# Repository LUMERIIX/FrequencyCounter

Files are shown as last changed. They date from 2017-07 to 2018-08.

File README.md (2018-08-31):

# FrequencyCounter - The most powerfull DIY FrequnecyCounter
## Introduction
FrequencyCounter is a soft- and hardware project which is a FPGA based FrequencyCounter. The FrequencyCounter is controlled by an GUI Interface ([SigrokLcd](https://github.com/LUMERIIX/SigrokLcd) )on the usb connected Host-PC. A single USB cable for Data and Power supply keeps the construction simple and clean as possible. The GUI is custom-made for this project behind the GUI runs [Sigrok](https://sigrok.org/) a open-source tool for controlling measure devices like frequency counters, multimeters, oscilloscopes etc. The project aims to be a simple, cheap, useful and accurate measure device for everyone. The layout is made in [KiCad]( http://kicad-pcb.org/) a open-source layout tool. The Project is open and everyone is wellcome to work on this project and contribute his extensions and improvements.

## Concept
Comming Soon!

## Hardware
The Hardware is based on a Spartan 6 FPGA which is the heartpiece of the entire circuit. The circuit is reduced to its minimal. The PCB ist a four-layer 1.6mm thick FR4 Board which makes it more expensive but the layout is much cleaner and the signal quality can be increased. The PCB has mounted components on top and bottom site of it. The Mounting on the bottom site is reduced to the minimal to keep it simple an allows also the use without a hosing.<br> 

### Housing
I created a simple and clean plexiglas housing for the PCB which fits the style of the prject very well. The design of the housing is inspired by the [Sick of Beige](http://dangerousprototypes.com/docs/Sick_of_Beige_compatible_cases) cases.<br> 

### Internal Clock Reference
The mouting of the Circuit give you the choice to mout the expensive **OCXO**(Oven Controlled Oscillator) or the way cheaper **VCTCXO**(Voltage Controller Temperatur Compensated Oscillator). In fact of this the precicion of the tool is scalable but I recommend you to mount the cheaper option because the difference in the accuracy is not as much as the price difference. <br>

### Input Circuits
The Input Circuits of each channel are different because not one of them fit in all usage situations.<br> 
The input circuit of **CHA** is realized with an voltage limiter and a HP-Filter at the inlet, followed by a divider (/8) with a HP-Filter and a voltage divider at the output to change the bias point. The change of the bias point is neccessary for the fpga to allow the signal detection.<br>
The most complex incput circuit is the one of the **external reference** (Ext.Ref). The circuit is out of the LTC6957 Datasheet and is often used for reference clocks. The transformator at the inlet make it impossible to use this circuit for both other channels of the FrequencyCounter (frequnecy reasons).<br>
**Channel B** is simpler than the other input ciruits. After the inlet it follows a voltage limiter and a very-fast comparator for edge detecting.<br>
### Communication
The Communication of the Device is over USB/UART through this its possible to have only one cable for programming, powersupply and also communication. On the PCB of the Counter a FTDI (FT2232) is mounted. Through this chip it's possible to programm the FPGA with JTAG and also have a USART Bus to the FPGA for the communication and the data. The Protocol which is used for the controlling consits only out of one command-byte which controls the hole device. The Commands you see in the Command Overview.<br>
**Command Overview**<br><br>
<br><br>
**Communication Overview**<br><br>
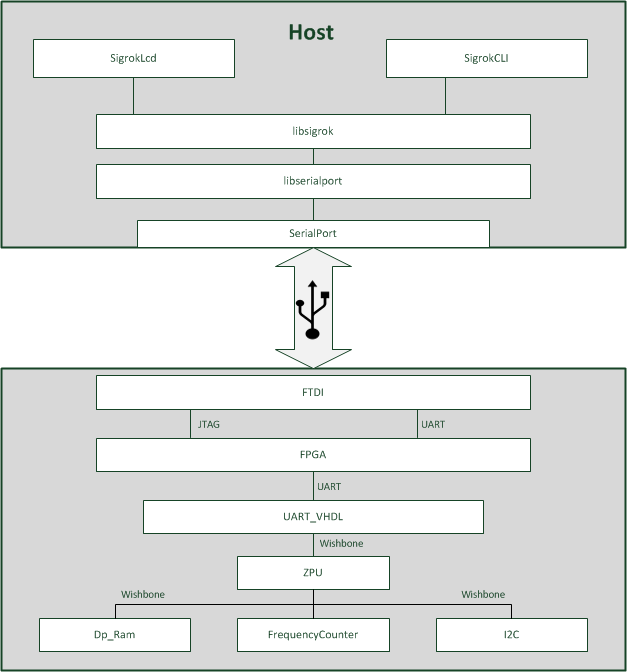
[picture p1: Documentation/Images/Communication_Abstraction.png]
<br>

### Hardware Overview:<br>
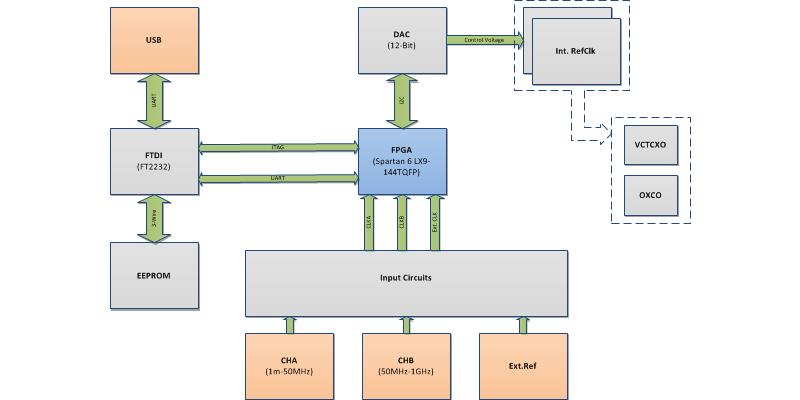
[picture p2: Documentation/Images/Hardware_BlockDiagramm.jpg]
<br>

## Software
### VHDL
**UART**<br>
The UART component isn't self written it is a adjusted version of the [UART component of Scott Larson](https://eewiki.net/pages/viewpage.action?pageId=59507062) of the eewiki. The component was extended by a Wishbone Interface to fit the projects architecture. The UART interface is used for the communication with the host-pc.<br><br>
**I2C**<br>
The I2C Master Component is also not self written it's base is from [opencores](https://opencores.org/project,i2c?do=projects&download=i2c). The component works fine and it's a big advantage to have a originally wishbone interface included. I2C is in the FrequnecyCounter used to control the DAC wich provides to control voltage for the oscillators.<br><br>
**ZPU**<br>
The [ZPU](https://github.com/zylin/zpu) is a open-source VHDL project from github wich includes a small 32bit CPU. The base ZPU Repo consist of different cores and testbenches but is very confusing. In fact of this I created a fork of the repo and set up a [working base](https://github.com/LUMERIIX/zpu) for the FrequencyCounter Project.<br><br>
**FrequencyCounter**<br>
The FrequencyCounter VHDL Code is the main part which counts our signals. The FrequencyCounter includes a ChannelSelctor which connect the desired Channels to the Counter itself. Furthermore the component includes a GateTimeGenerator which open a Countergate for a selected duration of time. The Signals are counted simultaneously with two identical VHDL counters. Each counter counts the amout of signal periods in this GateTime. Through the knowledge of the constant reference and the countervalue of the Reference Clock we can calculate the frequency of the unknown signal. This kind of Counter is called [Recirprocal Counter](https://en.wikipedia.org/wiki/Frequency_counter).<br><br>
**Procedure & Calculation**<br><br>
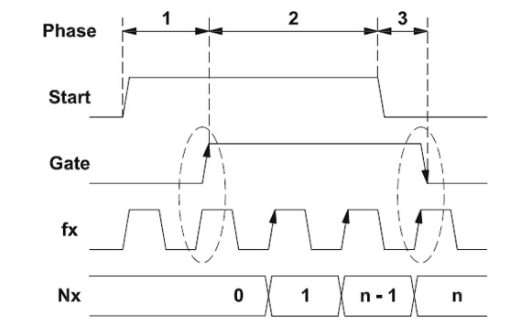
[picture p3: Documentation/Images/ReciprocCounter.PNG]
<br><br>

<br><br><br><br><br><br><br><br><br><br>

**VHDL Abstraction**<br><br>
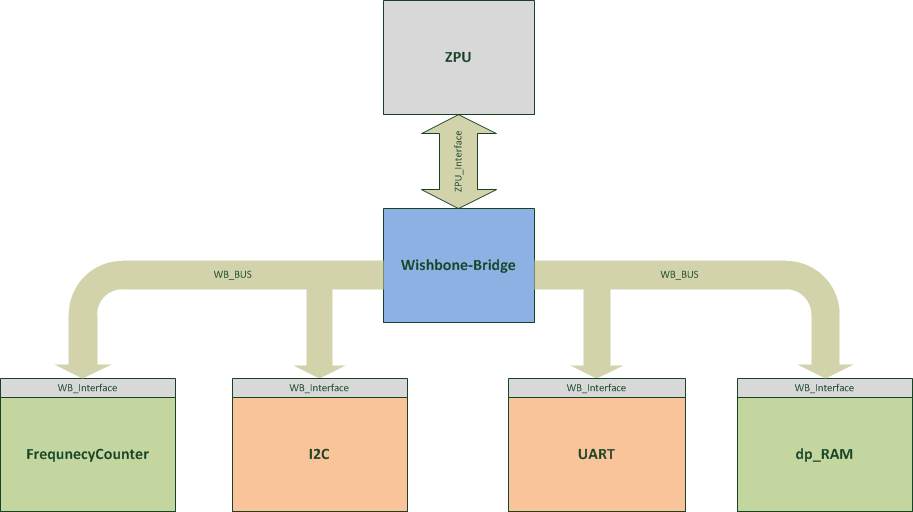
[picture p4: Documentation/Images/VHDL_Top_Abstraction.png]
<br><br>
**VHDL FrequencyCounter Abstraction**<br><br>
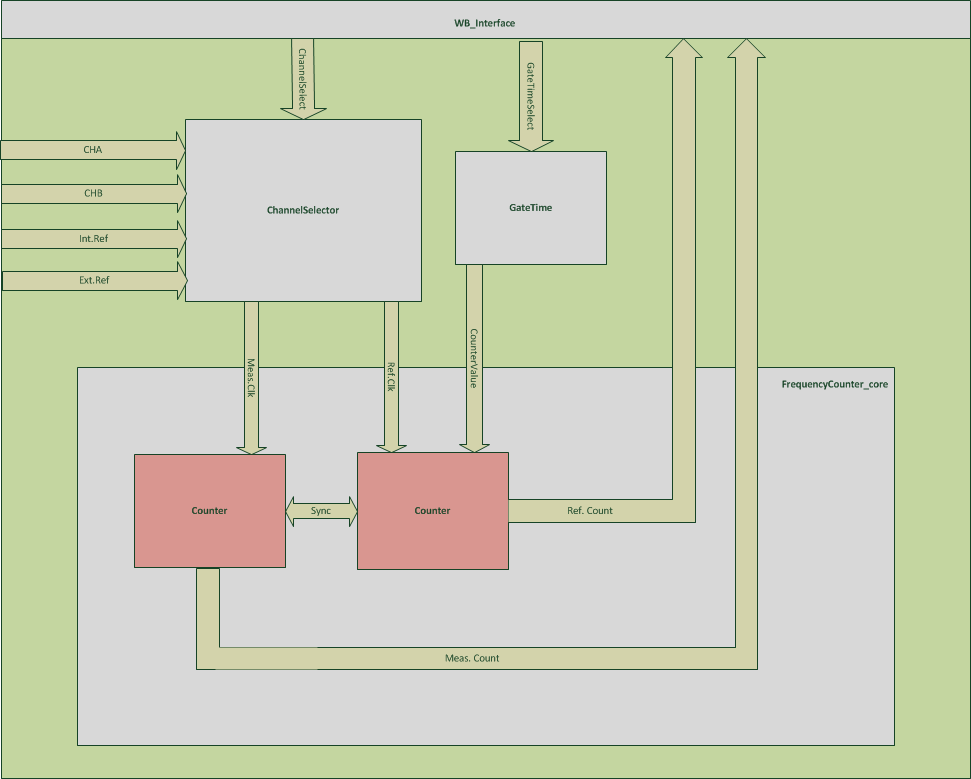
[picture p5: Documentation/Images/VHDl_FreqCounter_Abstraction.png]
<br>
### C-Code
The C-Code is the Programm Code for the implemented VHDL CPU [ZPU](https://github.com/zylin/zpu) or a so called [SOC](https://en.wikipedia.org/wiki/System_on_a_chip)(System-on-a-Chip). The C-Code implements the Protocol for the communication over uart and i2c. The ZPU also controls the entire VHDL Components and handles the data. The Code is obviously written in C and is based on a state-machine. The C-Code is converted in a dualported-RAM (VHDL Component) which is located in the VHDL Project and is connected to the Wishbone-Bus of the ZPU. 

## Download & Installation
**It's recommended to use a Linux Host-PC the project is tested and developt on Fedora 27 so I recommend to install a Fedora VM in VMWare Worksation**

```
cd
gedit .bashrc
```
Add following lines:
```
export PKG_CONFIG_PATH=/usr/local/lib/pkgconfig/ 
export PYTHONPATH=/usr/local/lib64/python2.7/site-packages/
```
Save and Close gedit.<br>
Install dependencies:
```
sudo dnf install gcc-gfortran apr-devel apr-util-devel octave*
sudo dnf install gcc-c++
sudo dnf update
sudo dnf upgrade
sudo svn git cppunit-devel rabbitvcs*
sudo dnf copr enable jenslody/codeblocks
sudo dnf install codeblocks codeblocks-contrib
sudo dnf install libftdi-devel libusb-devel xterm
sudo dnf install automake libtool autoconf make cmake autoconf-archive pkgconfig glib2-devel libzip-devel check-devel doxygen
sudo dnf install glibmm24-devel python-devel numpy pygobject3-devel swig
sudo dnf install redhat-rpm-config python3-devel qt5 qt5-devel boost-devel
```
Next Install libserialport and the adjusted version of libsigrok:
```
git clone git://sigrok.org/libserialport
cd /libserialport
./autogen.sh 
./configure
make
sudo make install

git clone https://github.com/LUMERIIX/libsigrok_FreqCount
cd libsigrok_FreqCount
./autogen.sh
PKG_CONFIG_PATH=/usr/local/lib/pkgconfig/ ./configure 
make -j4
sudo PKG_CONFIG_PATH=/usr/local/lib/pkgconfig/ PYTHONPATH=/usr/local/lib64/python2.7/site-packages/ make install
sudo ldconfig /usr/local/lib
```
Download the FrequencyCounter Repo:
```
git clone https://github.com/LUMERIIX/FrequencyCounter
cd FrequencyCounter 
```
**Optional** Download the fork of the ZPU Repo to have all source files 
```
cd
git clone https://github.com/LUMERIIX/zpu
```
The source files are located under
```
cd zpu/zpu/hdl/zpu4
```
Next Install openocd for flashing the bitstream:
```
sudo dnf install git libtool autoconf texinfo libusb-dev
sudo dnf install libftdi
cd
git clone git://git.code.sf.net/p/openocd/code openocd
cd ~/openocd
./bootstrap
./configure --enable-maintainer-mode --disable-werror --enable-ftdi
make
sudo make install
```
Create Directory for Config files of Openocd
```
cd ~
mkdir openocd-bin
cd ~/openocd/tcl
cp -r * ~/openocd-bin
cd ../src
cp openocd ~/openocd-bin
```
Add the Interface Config file for the FT2232
```
cd 
cp FrequnecyCounter/FTDI/ft2232-jtag.cfg openocd-bin/interface/ftdi
```
Download [SigrokLcd](https://github.com/LUMERIIX/SigrokLcd) or [SigrokCLI](https://sigrok.org/wiki/Linux)

### Set up the FTDI Chip (FT2232d)
First download [FT_PROG](http://www.ftdichip.com/Support/Utilities.htm#FT_PROG) and install it on your Host-pc.<br>
Open FT_PROG and Load FrequencyCounter.xml Template from directrory /FrequnceyCounter/Documentation/FrequencyCounter_Template.xml<br>
Connect your FrequencyCounter via USB to the Host-PC and power it!<br>
**Check first the Voltages of the Powersupply on the PCB to make sure the circuit is working correctly!**<br>
Scan for Devices (Devices --> Scan&Parse)<br>
A Device with Chip Type: FT2232D should be listed in the Device Tree on the left.<br>
Program Template on FTDI Chip (Devices --> Program)<br>
Now your FTDI Chip should be set-up correctly
Else take a look in the [FT_PROG manual](http://www.ftdichip.com/Support/Documents/AppNotes/AN_124_User_Guide_For_FT_PROG.pdf)

## How to use it
The actual bitstream you find under /bitstream:
```
cd
cd FrequencyCounter/bitstream
```
To flash the bitstream move to the openocd directory
```
cd
cd openocd
mdkdir bitstream
cp ../FrequencyCounter/bitstream/frequencycountertop.bit bitstream
```
Flash Command
```
openocd -f interface/ftdi/ft2232-jtag.cfg -f cpld/xilinx-xc6s.cfg -c "init; xc6s_program xc6s.tap; pld load 0 bitstream/frequnecycountertop.bit; exit"
```
**If a error is thrown try it as root.
And change write permission of the USB port where the Hardware is connected and try again!**

Open SigrokLcd and try to get some Data
```
cd
cd SigrokLcd/bin/Release
./SigrokLcd
```
If the GUI doesn't exit and you can finish the configuration of the connection in SigrokLcd you handled the bigest step. 
The Preset for the ChannelSelect is on CHA so you should receive a Frequency of quite a feq MHz. This Frequency exists through the output voltage swing of the frequency divider.<br>
**Congrats it seems that your DIY FrequencyCounter works!**

### Contact
If you have a Problem, a improvment or need Information don't hesitate to contact me.<br>
email: lukas.jenni@hotmail.de

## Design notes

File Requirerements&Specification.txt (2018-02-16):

Requirements&Specification 			-- Frequencycounter

-Frequencyrange: 					1mHz - 1GHz  						//Reduktion des Bereiches auf 500MHz möglich 
-PowerSupply: 						USB (Typ. B) => 	5V				
-Timebase options: 					ext. Reference 	 / int. Reference
-FPGA Clock: 						10MHz					
-InputVoltageRange: 				20mVpp - 5Vpp
-Signaltransfer DEVICE-PC: 			UART / JTAG							//FT2232
-DAC with eeprom:					ControllVoltageOCXO					//Aus FOM
-Quarz UART/USB: 					8MHz,12MHz							//seperater Quarz zum Betrieb der Schnittstelle
-FrequencyDisplay: 					Frequencycounter GUI
-Timebase intern: 					calibratable TCXO, OCXO				//10MHz
-Power:								max. 2.5W
-VoltageRegulator:					3.3V								//PowerSupply FPGA

Inputs:
Channel A							=> 1mHz - 50MHz
Channel B							=> 50MHz - 1GHz
Channel Ext. Ref

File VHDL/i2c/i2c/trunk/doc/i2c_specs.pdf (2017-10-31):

I

2

# C-Master Core Specification

# Author: Richard Herveille

### rherveille@opencores.org

### Rev. 0.9 July 3, 2003

## This page has been intentionally left blank

### Revision History

Rev. | Date | Author | Description
0.1 | 17/02/01 | Richard Herveille | First draft release
0.2 | 01/03/01 | Richard Herveille | Some cleaning up throughout the document Added ‘Programming Examples’ section
0.3 | | Richard Herveille | Added some comments after core-changes - added BUSY bit (status register) - changed I2C IO for ASIC support - added comment for FGPA IO
0.4 | 10/19/01 | Richard Herveille | Changed core’s databus size to 8bit. Changed documentation to reflect changes. Changed port names to new naming convention.
0.5 | 18/02/02 | Richard Herveille | Changed table headers. Added OpenCores logo.
0.5a | 05/02/02 | Richard Herveille | Reviewed entire document.
0.6 | 21/03/02 | Richard Herveille | Added Appendix A, Synthesis Results
0.7 | 25/06/02 | Richard Herveille | Changed Prescale Register formula
0.8 | 30/12/02 | Richard Herveille | Added Multi-Master capabilities. New timing diagrams.
0.9 | 03/07/03 | Richard Herveille | Changed ‘0x5C’ to ‘0xAC’ in Example1. Changed ‘RW’ to ‘W’ in Command Register. Changed ‘RW’ to ‘W’ in Transmit Register.

OpenCores | I²
C-Master core | 7/3/2003
www.opencores.org | Rev 0.8 Preliminary | 1 of 15

1

# Introduction

I

2
C is a two-wire, bi-directional serial bus that provides a simple and efficient method of data exchange between devices. It is most suitable for applications requiring occasional communication over a short distance between many devices. The I²
C standard is a true
multi-master bus including collision detection and arbitration that prevents data corruption if two or more masters attempt to control the bus simultaneously.

The interface defines 3 transmission speeds:
- Normal: 100Kbps
- Fast: 400Kbps
- High speed: 3.5Mbps

Only 100Kbps and 400Kbps modes are supported directly. For High speed special IOs are needed. If these IOs are available and used, then High speed is also supported.

## FEATURES

- Compatible with Philips I²
C standard
- Multi Master Operation
- Software programmable clock frequency
- Clock Stretching and Wait state generation
- Software programmable acknowledge bit
- Interrupt or bit-polling driven byte-by-byte data-transfers
- Arbitration lost interrupt, with automatic transfer cancelation
- Start/Stop/Repeated Start/Acknowledge generation
- Start/Stop/Repeated Start detection
- Bus busy detection
- Supports 7 and 10bit addressing mode
- Operates from a wide range of input clock frequencies
- Static synchronous design
- Fully synthesizable

2

# IO ports

## 2.1 Core Parameters

Parameter | Type | Default | Description
ARST_LVL | Bit | 1’b0 | Asynchronous reset level

### 2.1.1 ARST_LVL

The asynchronous reset level can be set to either active high (1’b1) or active low (1’b0).

## 2.2 WISHBONE interface signals

Port | Width | Direction | Description
wb_clk_i | 1 | Input | Master clock
wb_rst_i | 1 | Input | Synchronous reset, active high
arst_i | 1 | Input | Asynchronous reset
wb_adr_i | 3 | Input | Lower address bits
wb_dat_i | 8 | Input | Data towards the core
wb_dat_o | 8 | Output | Data from the core
wb_we_i | 1 | Input | Write enable input
wb_stb_i | 1 | Input | Strobe signal/Core select input
wb_cyc_i | 1 | Input | Valid bus cycle input
wb_ack_o | 1 | Output | Bus cycle acknowledge output
wb_inta_o | 1 | Output | Interrupt signal output

The core features a WISHBONE RevB.3 compliant WISHBONE Classic interface. All output signals are registered. Each access takes 2 clock cycles.
arst_i is not a WISHBONE compatible signal. It is provided for FPGA implementations. Using [arst_i] instead of [wb_rst_i] can result in lower cell-usage and higher performance, because most FPGAs provide a dedicated asynchronous reset path. Use either [arst_i] or [wb_rst_i], tie the other to a negated state.

## 2.3 External connections

Port | Width | Direction | Description
scl_pad_i | 1 | Input | Serial Clock line input
scl_pad_o | 1 | Output | Serial Clock line output
scl_pad_oe | 1 | Output | Serial Clock line output enable
sda_pad_i | 1 | Input | Serial Data line input
sda_pad_o | 1 | Output | Serial Data line output
sda_pad_oe | 1 | Output | Serial Data line output enable

The I²
C interface uses a serial data line (SDA) and a serial clock line (SCL) for data transfers. All devices connected to these two signals must have open drain or open collector outputs. Both lines must be pulled-up to VCC by external resistors.

The tri-state buffers for the SCL and SDA lines must be added at a higher hierarchical level. Connections should be made according to the following figure:

For FPGA designs the compiler can automatically insert these buffers using the following VHDL code:

scl <= scl_pad_o when (scl_padoen_oe = ‘0’) else ‘Z’;
sda <= sda_pad_o when (sda_padoen_oe = ‘0’) else ‘Z’;
scl_pad_i <= scl;
scl_pad_i <= sda;

Verilog code:

assign scl = scl_padoen_oe ? 1’bz : scl_pad_o; assign sda = sda_padoen_oe ? 1’bz: sda_pad_o; assign scl_pad_i = scl;
assign sda_pad_i = sda;

scl_pad_i

scl_pad_o

scl_padoen_o
sda_pad_i

sda_pad_o

sda_padoen_o

SCL

SDA

3

# Registers

## 3.1 Registers list

Name | Address | Width | Access | Description
PRERlo | 0x00 | 8 | RW | Clock Prescale register lo-byte
PRERhi | 0x01 | 8 | RW | Clock Prescale register hi-byte
CTR | 0x02 | 8 | RW | Control register
TXR | 0x03 | 8 | W | Transmit register
RXR | 0x03 | 8 | R | Receive register
CR | 0x04 | 8 | W | Command register
SR | 0x04 | 8 | R | Status register

## 3.2 Register description

### 3.2.1 Prescale Register

This register is used to prescale the SCL clock line. Due to the structure of the I² C
interface, the core uses a 5*SCL clock internally. The prescale register must be programmed to this 5*SCL frequency (minus 1). Change the value of the prescale register only when the ‘EN’ bit is cleared.

Example: wb_clk_i = 32MHz, desired SCL = 100KHz
1 | 63 ( | ) | 3 ( | ) 5 100
32 | dec | F hex
KHz
MHz prescale | − = | = ∗ =

Reset value: 0xFFFF

### 3.2.2 Control register

Bit # | Access | Description
7 | RW | EN, I² C core enable bit. When set to ‘1’, the core is enabled. When set to ‘0’, the core is disabled.
6 | RW | IEN, I² C core interrupt enable bit. When set to ‘1’, interrupt is enabled. When set to ‘0’, interrupt is disabled.
5:0 | RW | Reserved
Reset Value: 0x00

The core responds to new commands only when the ‘EN’ bit is set. Pending commands are finished. Clear the ‘EN’ bit only when no transfer is in progress, i.e. after a STOP command, or when the command register has the STO bit set. When halted during a transfer, the core can hang the I²
C bus.

### 3.2.3 Transmit register

Bit # | Access | Description
7:1 | W | Next byte to transmit via I² C
0 | W | In case of a data transfer this bit represent the data’s LSB. In case of a slave address transfer this bit represents the RW bit. ‘1’ = reading from slave ‘0’ = writing to slave

Reset value: 0x00

### 3.2.4 Receive register

Bit # | Access | Description
7:0 | R | Last byte received via I² C
Reset value: 0x00

### 3.2.5 Command register

Bit # | Access | Description
7 | W | STA, generate (repeated) start condition
6 | W | STO, generate stop condition
5 | W | RD, read from slave
4 | W | WR, write to slave
3 | W | ACK, when a receiver, sent ACK (ACK = ‘0’) or NACK (ACK = ‘1’)
2:1 | W | Reserved
0 | W | IACK, Interrupt acknowledge. When set, clears a pending interrupt.
Reset Value: 0x00

The STA, STO, RD, WR, and IACK bits are cleared automatically. These bits are always read as zeros.

### 3.2.6 Status register

Bit # | Access | Description
7 | R | RxACK, Received acknowledge from slave. This flag represents acknowledge from the addressed slave. ‘1’ = No acknowledge received ‘0’ = Acknowledge received
6 | R | Busy, I² C bus busy ‘1’ after START signal detected ‘0’ after STOP signal detected
5 | R | AL, Arbitration lost This bit is set when the core lost arbitration. Arbitration is lost when: • a STOP signal is detected, but non requested • The master drives SDA high, but SDA is low. See bus-arbitration section for more information.
4:2 | R | Reserved
1 | R | TIP, Transfer in progress. ‘1’ when transferring data ‘0’ when transfer complete
0 | R | IF, Interrupt Flag. This bit is set when an interrupt is pending, which will cause a processor interrupt request if the IEN bit is set. The Interrupt Flag is set when: • one byte transfer has been completed • arbitration is lost

Reset Value: 0x00

Please note that all reserved bits are read as zeros. To ensure forward compatibility, they should be written as zeros.

4

# Operation

## 4.1 System Configuration

The I²
C system uses a serial data line (SDA) and a serial clock line (SCL) for data transfers. All devices connected to these two signals must have open drain or open collector outputs. The logic AND function is exercised on both lines with external pull-up resistors.

Data is transferred between a Master and a Slave synchronously to SCL on the SDA line on a byte-by-byte basis. Each data byte is 8 bits long. There is one SCL clock pulse for each data bit with the MSB being transmitted first. An acknowledge bit follows each transferred byte. Each bit is sampled during the high period of SCL; therefore, the SDA line may be changed only during the low period of SCL and must be held stable during the high period of SCL. A transition on the SDA line while SCL is high is interpreted as a command (see START and STOP signals).

## 4.2 I² C Protocol

Normally, a standard communication consists of four parts:
1) START signal generation
2) Slave address transfer
3) Data transfer
4) STOP signal generation
S | A7 | A6 | A5 | A4 | A3 | A2 | A1 | RW ACK | D7 | D6 | D5 | D4 | D3 | D2 | D1 | D0 NACK | P

SCL

SDA

1 | 2 | 3 | 4 | 5 | 6 | 7 | 8 | 9
MSB | LSB
1 | 2 | 3 | 4 | 5 | 6 | 7 | 8 | 9
MSB | LSB

### 4.2.1 START signal

When the bus is free/idle, meaning no master device is engaging the bus (both SCL and SDA lines are high), a master can initiate a transfer by sending a START signal. A START signal, usually referred to as the S-bit, is defined as a high-to-low transition of SDA while SCL is high. The START signal denotes the beginning of a new data transfer. A Repeated START is a START signal without first generating a STOP signal. The master uses this method to communicate with another slave or the same slave in a different transfer direction (e.g. from writing to a device to reading from a device) without releasing the bus.

The core generates a START signal when the STA-bit in the Command Register is set and the RD or WR bits are set. Depending on the current status of the SCL line, a START or Repeated START is generated.

### 4.2.2 Slave Address Transfer

The first byte of data transferred by the master immediately after the START signal is the slave address. This is a seven-bits calling address followed by a RW bit. The RW bit signals the slave the data transfer direction. No two slaves in the system can have the same address. Only the slave with an address that matches the one transmitted by the master will respond by returning an acknowledge bit by pulling the SDA low at the 9th SCL clock cycle.

Note: The core supports 10bit slave addresses by generating two address transfers. See the Philips I²
C specifications for more details.

The core treats a Slave Address Transfer as any other write action. Store the slave device’s address in the Transmit Register and set the WR bit. The core will then transfer the slave address on the bus.

### 4.2.3 Data Transfer

Once successful slave addressing has been achieved, the data transfer can proceed on a byte-by-byte basis in the direction specified by the RW bit sent by the master. Each transferred byte is followed by an acknowledge bit on the 9th SCL clock cycle. If the slave signals a No Acknowledge, the master can generate a STOP signal to abort the data transfer or generate a Repeated START signal and start a new transfer cycle.

If the master, as the receiving device, does not acknowledge the slave, the slave releases the SDA line for the master to generate a STOP or Repeated START signal.

To write data to a slave, store the data to be transmitted in the Transmit Register and set the WR bit. To read data from a slave, set the RD bit. During a transfer the core set the TIP flag, indicating that a Transfer is In Progress. When the transfer is done the TIP flag is reset, the IF flag set and, when enabled, an interrupt generated. The Receive Register contains valid data after the IF flag has been set. The user may issue a new write or read command when the TIP flag is reset.

### 4.2.4 STOP signal

The master can terminate the communication by generating a STOP signal. A STOP signal, usually referred to as the P-bit, is defined as a low-to-high transition of SDA while SCL is at logical ‘1’.

## 4.3 Arbitration Procedure

### 4.3.1 Clock Synchronization

The I²
C bus is a true multimaster bus that allows more than one master to be connected on it. If two or more masters simultaneously try to control the bus, a clock synchronization procedure determines the bus clock. Because of the wired-AND connection of the I²
C signals a high to low transition affects all devices connected to the bus. Therefore a high to low transition on the SCL line causes all concerned devices to count off their low period. Once a device clock has gone low it will hold the SCL line in that state until the clock high state is reached. Due to the wired-AND connection the SCL line will therefore be held low by the device with the longest low period, and held high by the device with the shortest high period.

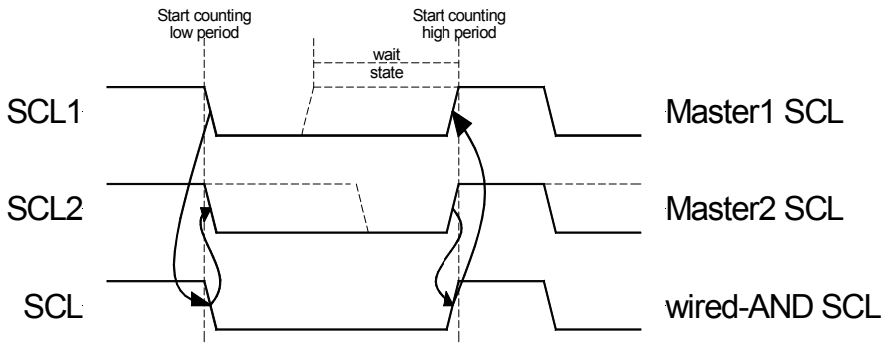
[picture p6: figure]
Start counting low period; wait state; Start counting high period; SCL1; SCL2; SCL; Master1 SCL; Master2 SCL; wired-AND SCL

### 4.3.2 Clock Stretching

Slave devices can use the clock synchronization mechanism to slow down the transfer bit rate. After the master has driven SCL low, the slave can drive SCL low for the required period and then release it. If the slave’s SCL low period is greater than the master’s SCL low period, the resulting SCL bus signal low period is stretched, thus inserting wait-states.

5

# Architecture

The I2C core is built around four primary blocks; the Clock Generator, the Byte Command Controller, the Bit Command Controller and the DataIO Shift Register. All other blocks are used for interfacing or for storing temporary values.

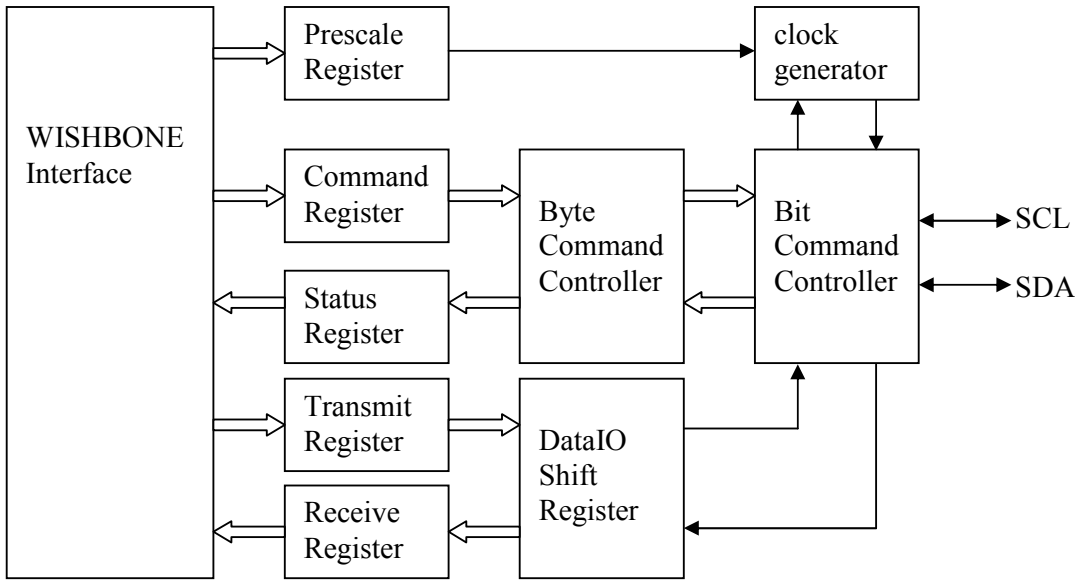
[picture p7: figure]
SCL; SDA; Prescale Register; clock generator; Command Register; Status Register; Byte Command Controller; Bit Command Controller; WISHBONE Interface; Transmit Register; Receive Register; DataIO Shift Register

## 5.1 Clock Generator

The Clock Generator generates an internal 4*Fscl clock enable signal that triggers all synchronous elements in the Bit Command Controller. It also handles clock stretching needed by some slaves.

## 5.2 Byte Command Controller

The Byte Command Controller handles I2C traffic at the byte level. It takes data from the Command Register and translates it into sequences based on the transmission of a single byte. By setting the START, STOP, and READ bit in the Command Register, for example, the Byte Command Controller generates a sequence that results in the

Fig. 5.1 Internal structure I2C Master Core

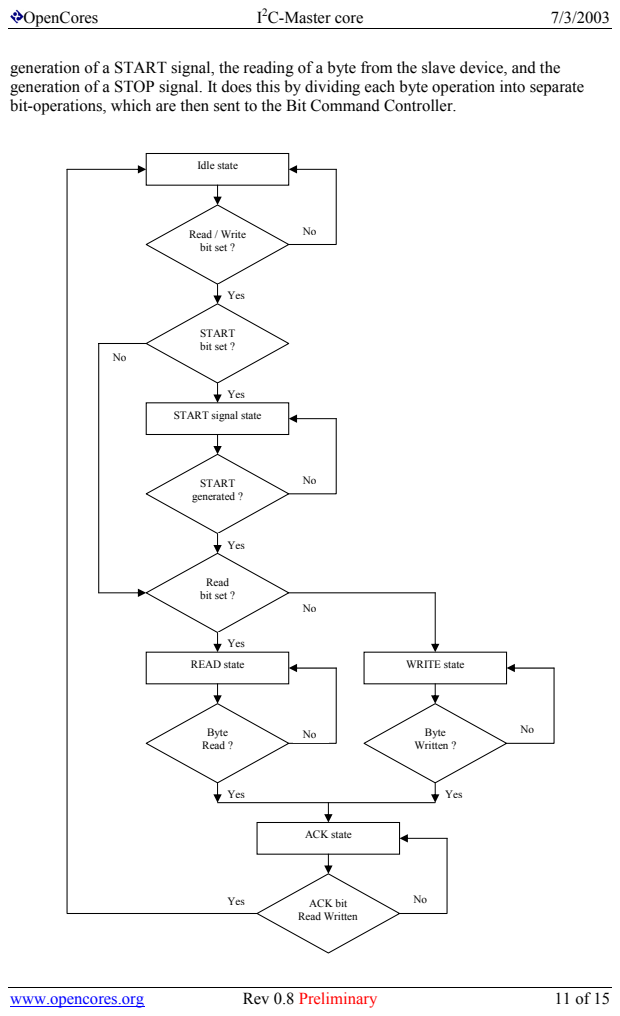
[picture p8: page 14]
Idle state; Read / Write bit set ?; Yes; START bit set ?; Read bit set ?; READ state; Byte Read ?; ACK state; WRITE state; Byte Written ?; ACK bit Read Written

generation of a START signal, the reading of a byte from the slave device, and the
generation of a STOP signal. It does this by dividing each byte operation into separate
bit-operations, which are then sent to the Bit Command Controller.

START signal state

START generated ?

## 5.3 Bit Command Controller

The Bit Command Controller handles the actual transmission of data and the generation of the specific levels for START, Repeated START, and STOP signals by controlling the SCL and SDA lines. The Byte Command Controller tells the Bit Command Controller which operation has to be performed. For a single byte read, the Bit Command Controller receives 8 separate read commands. Each bit-operation is divided into 5 pieces (idle and A, B, C, and D), except for a STOP operation which is divided into 4 pieces (idle and A, B, and C).

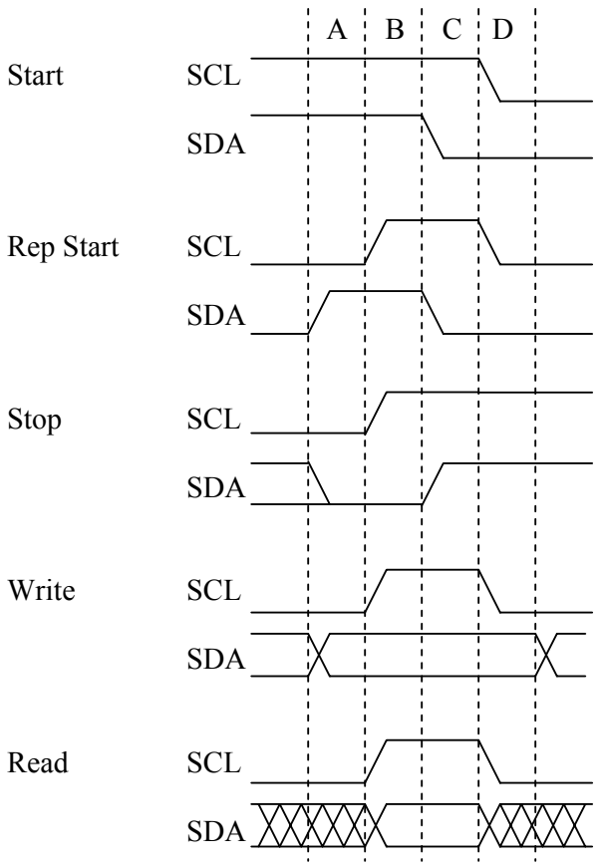
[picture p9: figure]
Start; SCL; SDA; Rep Start; Stop; Write; Read

## 5.4 DataIO Shift Register

The DataIO Shift Register contains the data associated with the current transfer. During a read action, data is shifted in from the SDA line. After a byte has been read the contents are copied into the Receive Register. During a write action, the Transmit Register’s contents are copied into the DataIO Shift Register and are then transmitted onto the SDA line.

6

# Programming examples

## Example 1

Write 1 byte of data to a slave.

Slave address = 0x51 (b”1010001”) Data to write = 0xAC

I2C Sequence:
1) generate start command
2) write slave address + write bit
3) receive acknowledge from slave
4) write data
5) receive acknowledge from slave
6) generate stop command

Commands:
1) write 0xA2 (address + write bit) to Transmit Register, set STA bit, set WR bit. -- wait for interrupt or TIP flag to negate --
2) read RxACK bit from Status Register, should be ‘0’.
write 0xAC to Transmit register, set STO bit, set WR bit.
-- wait for interrupt or TIP flag to negate --
3) read RxACK bit from Status Register, should be ‘0’.

Please note that the time for the Interrupt Service Routine is not shown here. It is assumed that the ISR is much faster then the I²
C cycle time, and therefore not visible.

## Example 2

Read a byte of data from an I2C memory device.

Slave address = 0x4E
Memory location to read from = 0x20

I2C sequence:
1) generate start signal
2) write slave address + write bit
3) receive acknowledge from slave
4) write memory location
5) receive acknowledge from slave
6) generate repeated start signal
7) write slave address + read bit
8) receive acknowledge from slave
9) read byte from slave
10) write no acknowledge (NACK) to slave, indicating end of transfer
11) generate stop signal

Commands:
1) write 0x9C (address + write bit) to Transmit Register, set STA bit, set WR bit. -- wait for interrupt or TIP flag to negate --
2) read RxACK bit from Status Register, should be ‘0’.
write 0x20 to Transmit register, set WR bit.
-- wait for interrupt or TIP flag to negate --
3) read RxACK bit from Status Register, should be ‘0’.
write 0x9D (address + read bit) to Transmit Register, set STA bit, set WR bit. -- wait for interrupt or TIP flag to negate --
4) set RD bit, set ACK to ‘1’ (NACK), set STO bit

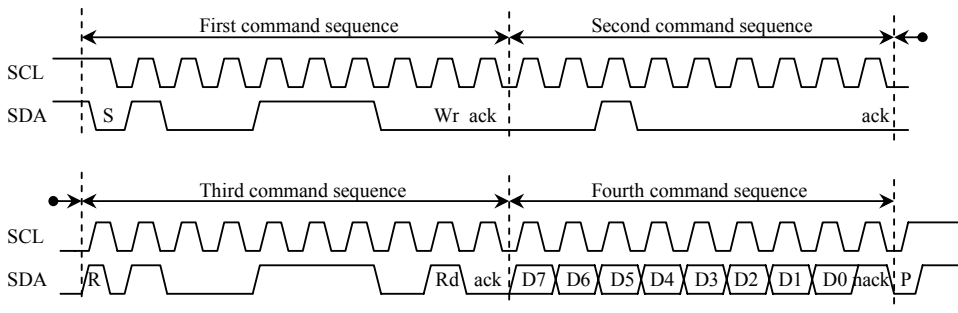
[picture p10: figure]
First command sequence; Second command sequence; SDA; Wr ack; ack; SCL; Third command sequence; Fourth command sequence

Please note that the time for the Interrupt Service Routine is not shown here. It is assumed that the ISR is much faster then the I²
C cycle time, and therefore not visible.
SDA | R | Rd ack | D7 D6 D5 D4 D3 D2 D1 D0 nack | P

# Appendix A

# Synthesis results

Synthesis tool: Synplify Pro

Technology | Device | Speed grade | Fmax | Resource usage
ACTEL | A54SX16ATQ100 | std | 58MHz | Modules: 352
Altera | EP10K50ETC144 | -3 | 82MHz | LCs: 294
| EP20K30ETC144 | -3 | 74MHz | ATOMS: 257
Xilinx | 2s15CS144 | -5 | 82MHz | LUTs: 229
| XCV50ECS144 | -8 | 118MHz | LUTs: 230

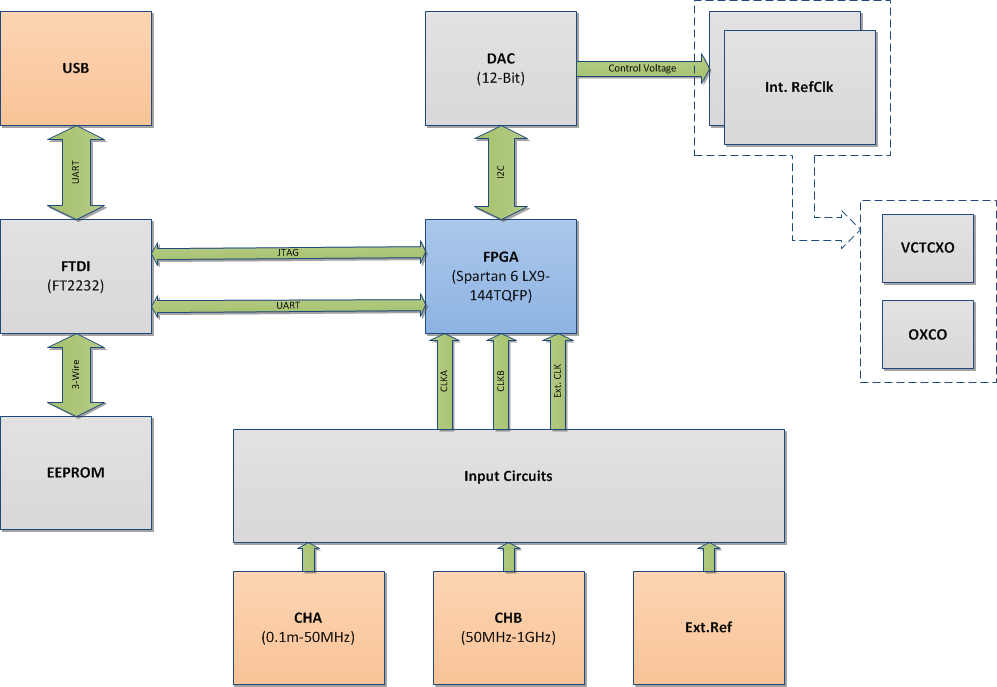
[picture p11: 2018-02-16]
Documentation/Images/Hardware_BlockDiagramm.png

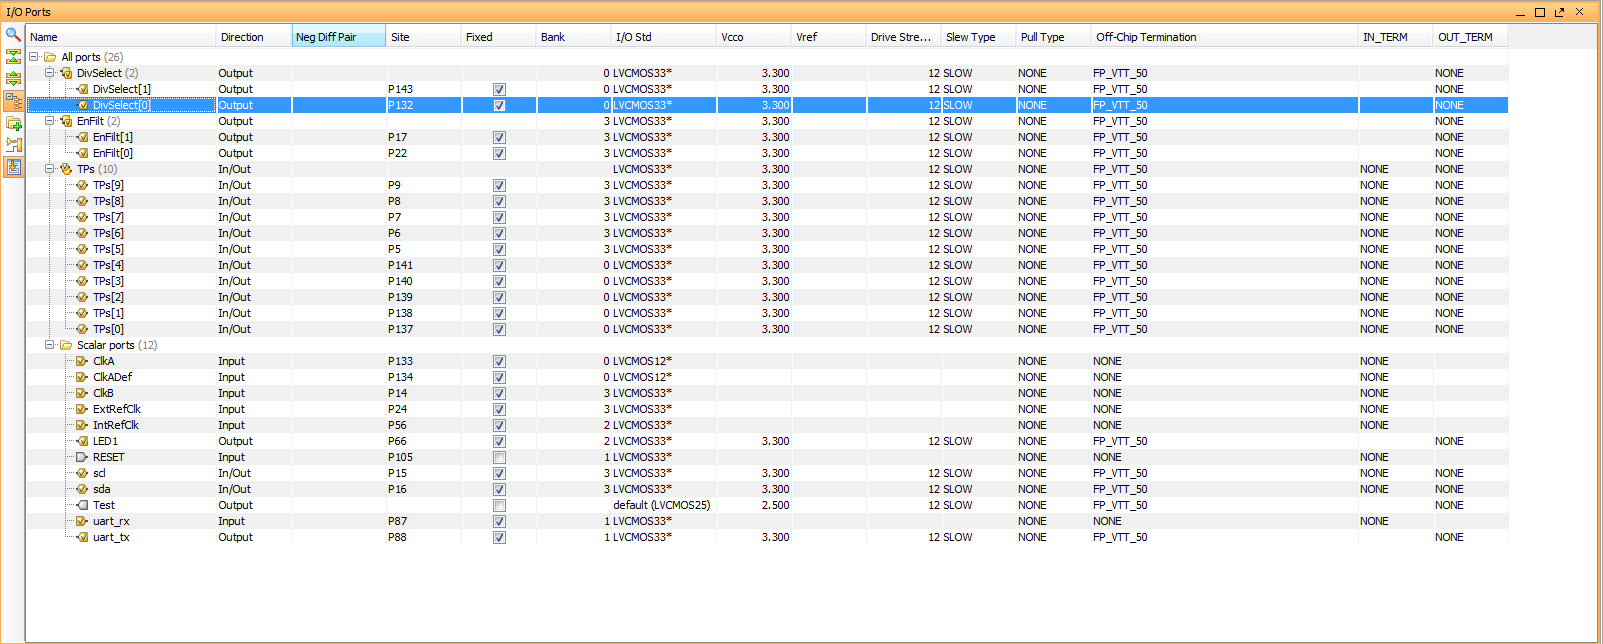
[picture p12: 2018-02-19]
bitstream/frequencycounter_pinout_v1.0.0.PNG

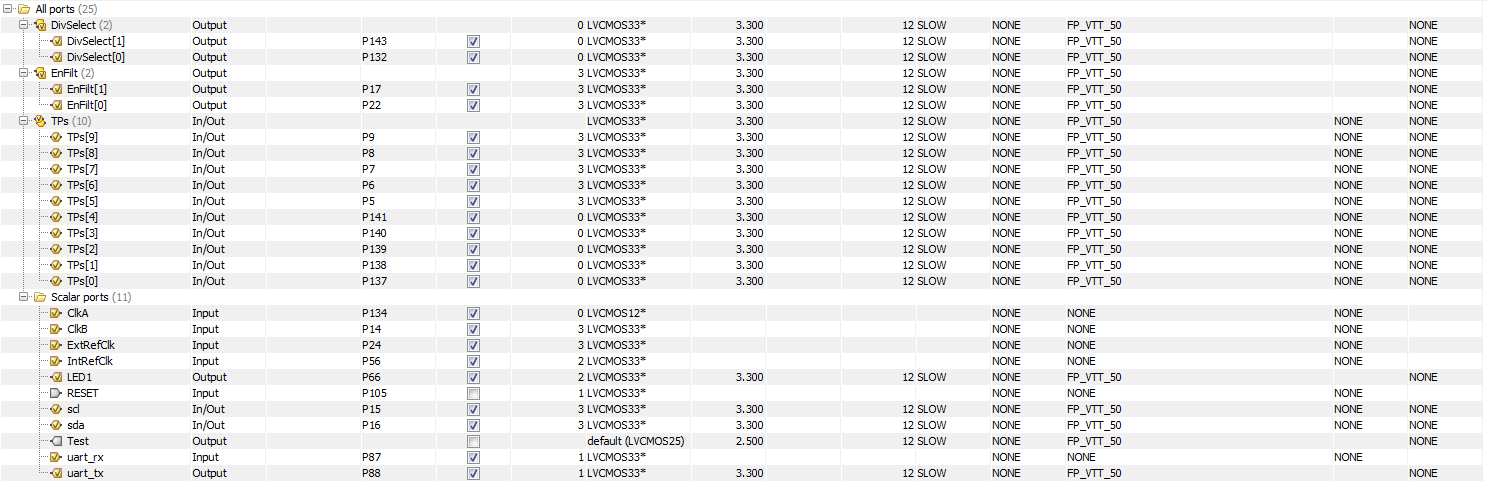
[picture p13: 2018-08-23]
bitstream/frequencycounter_pinout_v1.0.1.PNG

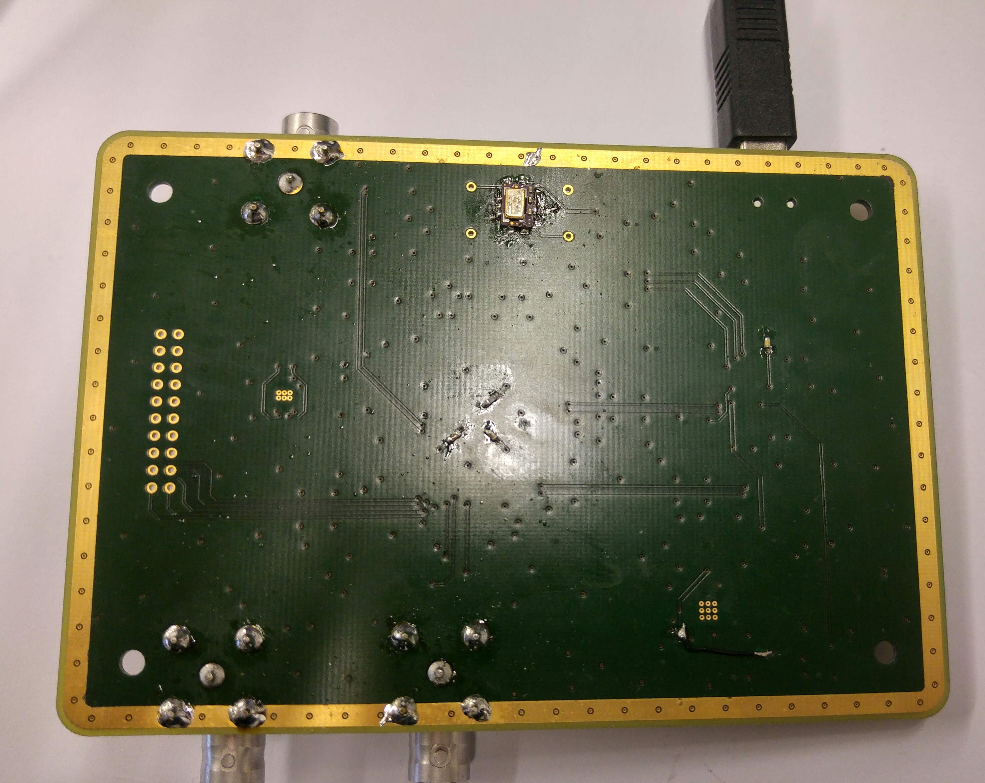
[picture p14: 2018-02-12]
Documentation/Images/20180112_162240_HDR.jpg

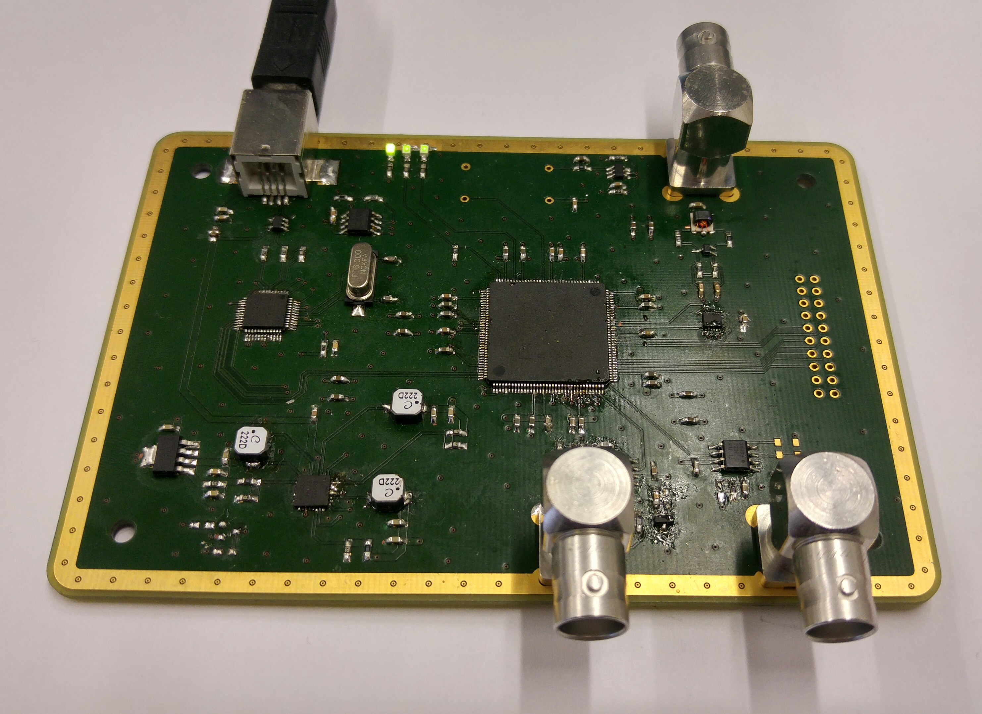
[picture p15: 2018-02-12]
Documentation/Images/20180112_162202_HDR.jpg

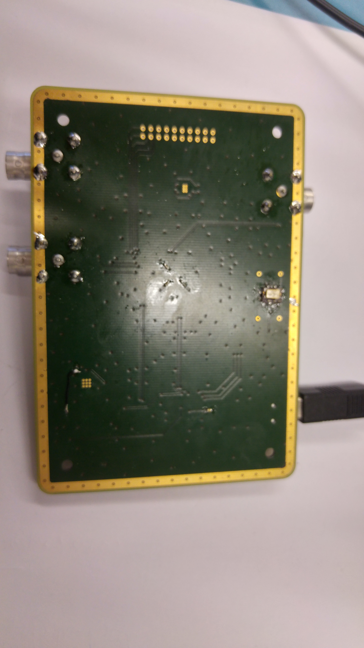
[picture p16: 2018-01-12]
Documentation/Images/Bot.jpg

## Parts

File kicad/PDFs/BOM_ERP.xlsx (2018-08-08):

 | Description | Part | References | Value | Quantity Per PCB | ERP Nr. | Kontrolle Footprint | Quantity to Order
1 | Unpolarized capacitor | C | C18 C22 C25 C26 C28 C29 C31 C32 C34 C35 | 0.47u | 10 | 120048 | x | 0 | MG-07
2 | Unpolarized capacitor | C | C7 C19 C23 C39 C42 C43 C44 C45 C46 C47 | 100n | 10 | 101653 | x | 0 | MG-07
3 | Unpolarized capacitor | C | C51 | 100p | 1 | 118123 | x | 0 | MG-07
4 | Unpolarized capacitor | C | C1 C2 C3 C4 C5 C6 C9 C10 C38 | 10u | 9 | 101654 | x | 0 | MG-07
5 | Unpolarized capacitor | C | C48 C49 | 1n | 2 | 101606 | x | 0 | MG-07
6 | Unpolarized capacitor | C | C8 C_I2C_1 C_I2C_2 C_JTAG_1 C_JTAG_2 C_RS2232_1 C_RS2232_2 C_TP_1 C_TP_2 | 1u | 9 | 101655 | x | 0 | MG-07
7 | Unpolarized capacitor | C | C40 C41 | 27p | 2 | 115705 | x | 0 | MG-07
8 | Unpolarized capacitor | C | C36 C37 | 33n | 2 | 120245 | x | 0 | MG-07
9 | Unpolarized capacitor | C | C11 C12 C13 C14 C15 C16 C17 C20 C21 C24 C27 C30 C33 | 4.7u | 13 | 121207 | x | 0 | MG-07
10 | BAV99 High-speed switching diodes | BAV99 | D3 | BAV99 | 1 | 100569 | x | 0 | SMD_DIO 04
11 | LED generic | LED | D1 D2 D11 | LED | 3 | 121890 | x | 0 | MG-13
12 | AOCJY1-100MHz | AOCJY1-100MHz | G1 | AOCJY1-100MHz | 1 |  | x | 1
13 | coaxial connector (BNC, SMA, SMB, SMC, Cinch/RCA, ...) | CONN_COAXIAL | J2 J3 J4 | CONN_COAXIAL | 3 | 102877 | x | 0 | RH-095
14 | USB Type B connector | USB_B | J1 | USB_B | 1 | 103294 | x | 0 | MG-015
15 | Inductor with Ferrite Core | L_Core_Ferrite | L1 L2 L3 | 2.2u | 3 | 101900 | x | 0 | SMD-L / 08
16 | Resistor | R | R27 | 1.5k | 1 | 115747 | x | 0 | SMD-R / 06
17 | Resistor | R | R30 R33 | 100R | 2 | 101265 | x | 0 | SMD-R / 06
18 | Resistor | R | R2 R5 | 100k | 2 | 115771 | x | 0 | SMD-R / 07
19 | Resistor | R | R10 R28 | 10k | 2 | 101335 | x | 0 | SMD-R / 08
20 | Resistor | R | R1 R4 | 180k | 2 | 118873 | x | 0 | SMD-R / 09
21 | Resistor | R | R16 R12 | 1k | 2 | 101266 | x | 0 | SMD-R / 10
22 | Resistor | R | R29 | 2.2k | 1 | 115749 | x | 0 | SMD-R / 11
23 | Resistor | R | R6 | 20k | 1 | 124818 | x | 0 | SMD-R / 12
24 | Resistor | R | R7 | 22k | 1 | 101285 | x | 0 | SMD-R / 13
25 | Resistor | R | R25 R26 | 27R | 2 | 101255 | x | 0 | SMD-R / 14
26 | Resistor | R | R8 R9 R11 | 4.7k | 3 | 101332 | x | 0 | SMD-R / 15
27 | Resistor | R | R24 | 470R | 1 | 101329 | x | 0 | SMD-R / 16
28 | Resistor | R | R32 | 47R | 1 | 115728 | x | 0 | SMD-R / 17
29 | Resistor | R | R34 | 50R | 1 | 101318 | x | 0 | SMD-R / 18
30 | Resistor | R | R31 | 560R | 1 | 101284 | x | 0 | SMD-R / 19
31 | Resistor | R | R14 R15 R17 R22 R39 | 680R | 5 | 114094 | x | 0 | SMD-R / 20
33 | TC1-1T | WBC16-1T | T1 | WBC16-1T | 1 |  | x | 1
34 | 6MHz_Crystal | 6MHz_Crystal | U7 | 6MHz_Crystal | 1 | 101939 | x | 0 | SMD-QUA / 09
35 | AT93C46DN-SH | AT93C46DN-SH | U8 | AT93C46DN-SH | 1 | 121360 | x | 0 | MG-02
36 | Full Speed Double Channel USB UART/FIFO, LQFP-48 | FT2232D | U6 | FT2232D | 1 | 125249 | x | 1 | MG-02
37 | LP3870 | LP3871 | U2 | LP3871 | 1 |  | x | 1
38 | LTC6957-2 | LTC6957-3 | U9 | LTC6957-3 | 1 | 124015 | x | 0 | MG-02
39 | MC12092 | MC12093 | U10 | MC12093 | 1 | 120174 | x | 0 | MG-02
40 | MCP4724 | MCP4725 | U3 | MCP4725 | 1 | 119755 | x | 0 | MG-02
41 | NFM18PS | NFM18PS | U4 | NFM18PS | 1 | 118877 | x | 0 | MG-07
42 | TLV3500 | TLV3501 | U12 | TLV3501 | 1 |  | x | 1
43 | TPS650249 | TPS650250 | U1 | TPS650250 | 1 |  | x | 1
44 | WE-TVS-824010 | WE-TVS-824011 | U5 | WE-TVS-824011 | 1 | 119885 | x | 0 | MG-04
45 | tx175 | tx176 | U11 | tx176 | 1 |  | x | 1
46 | HSMS-281C-TR1G | HSMS-281C-TR1G | V1 V2 | HSMS-281C-TR1G | 2 | 124016 | x | 0 | MG-04
47 | Header_2x10Pf-R2.54 | Header_2x10Pf-R2.54 | X1 | Header_2x10Pf-R2.54 | 1 | 125569 | x | 1
48 | xc6slx9_143 | xc6slx9_144 | xc6slx9_1 | xc6slx9_144 | 1 |  | x | 1
49 | 45V Vce, 0.8A Ic, NPN, SOT-23 | BC846B | Q1 | BC846B | 1 | 100616 | x | 0 | SMD_TR / 05
50 | Resistor | R | R13 | 150k | 1 | 117827 | x | 0 | MG-06
28 | Resistor | R | R18 R19 | 330R | 2 | 101264 | x | 0 | MG-06
Quantity of PCBs | 1
 |  |  |  |  |  |  |  | 2
acrylglas | 130x90x2 |4x3.4 Loch 10mm abstand | entgratet |10mm radius |  | 2

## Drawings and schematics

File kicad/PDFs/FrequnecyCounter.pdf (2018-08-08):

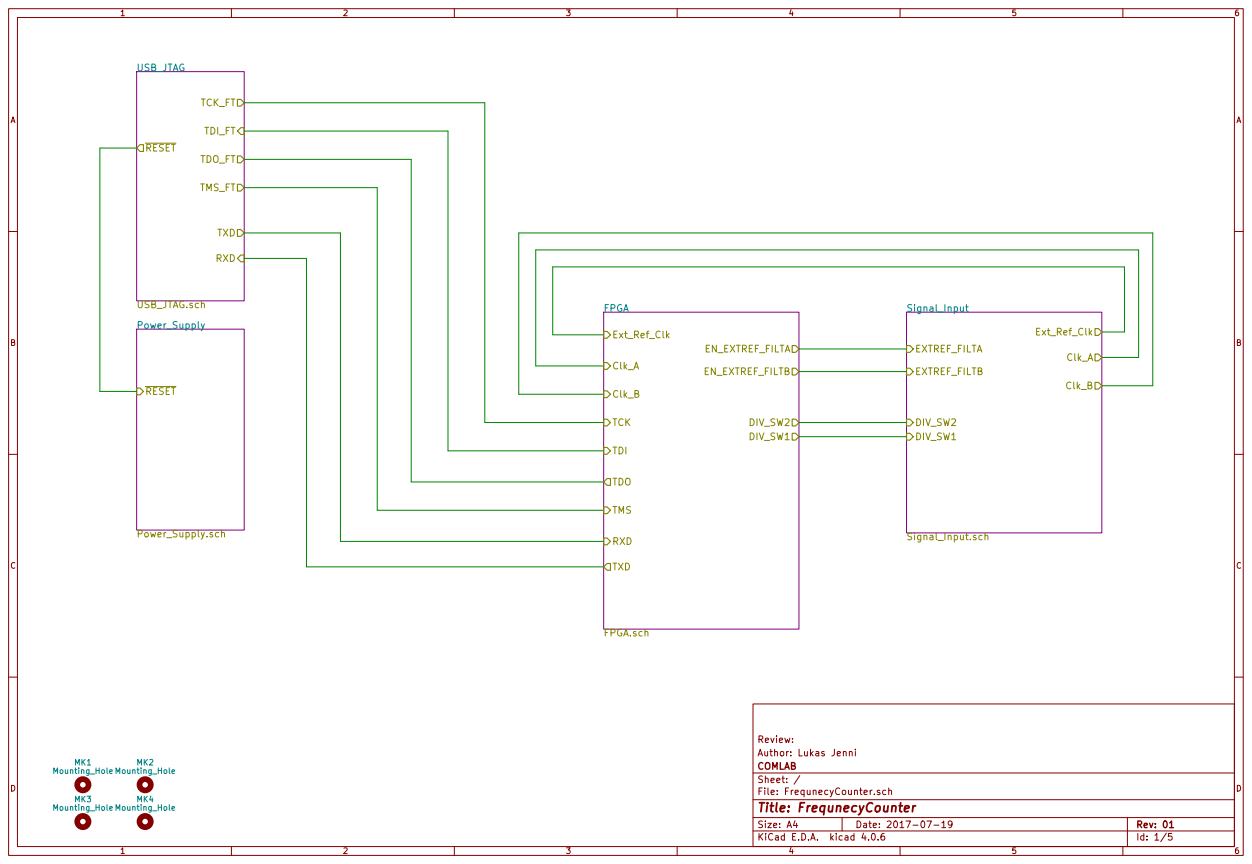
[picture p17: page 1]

Author: Lukas Jenni Review: Power_Supply

File: FrequnecyCounter.sch Sheet: / COMLAB

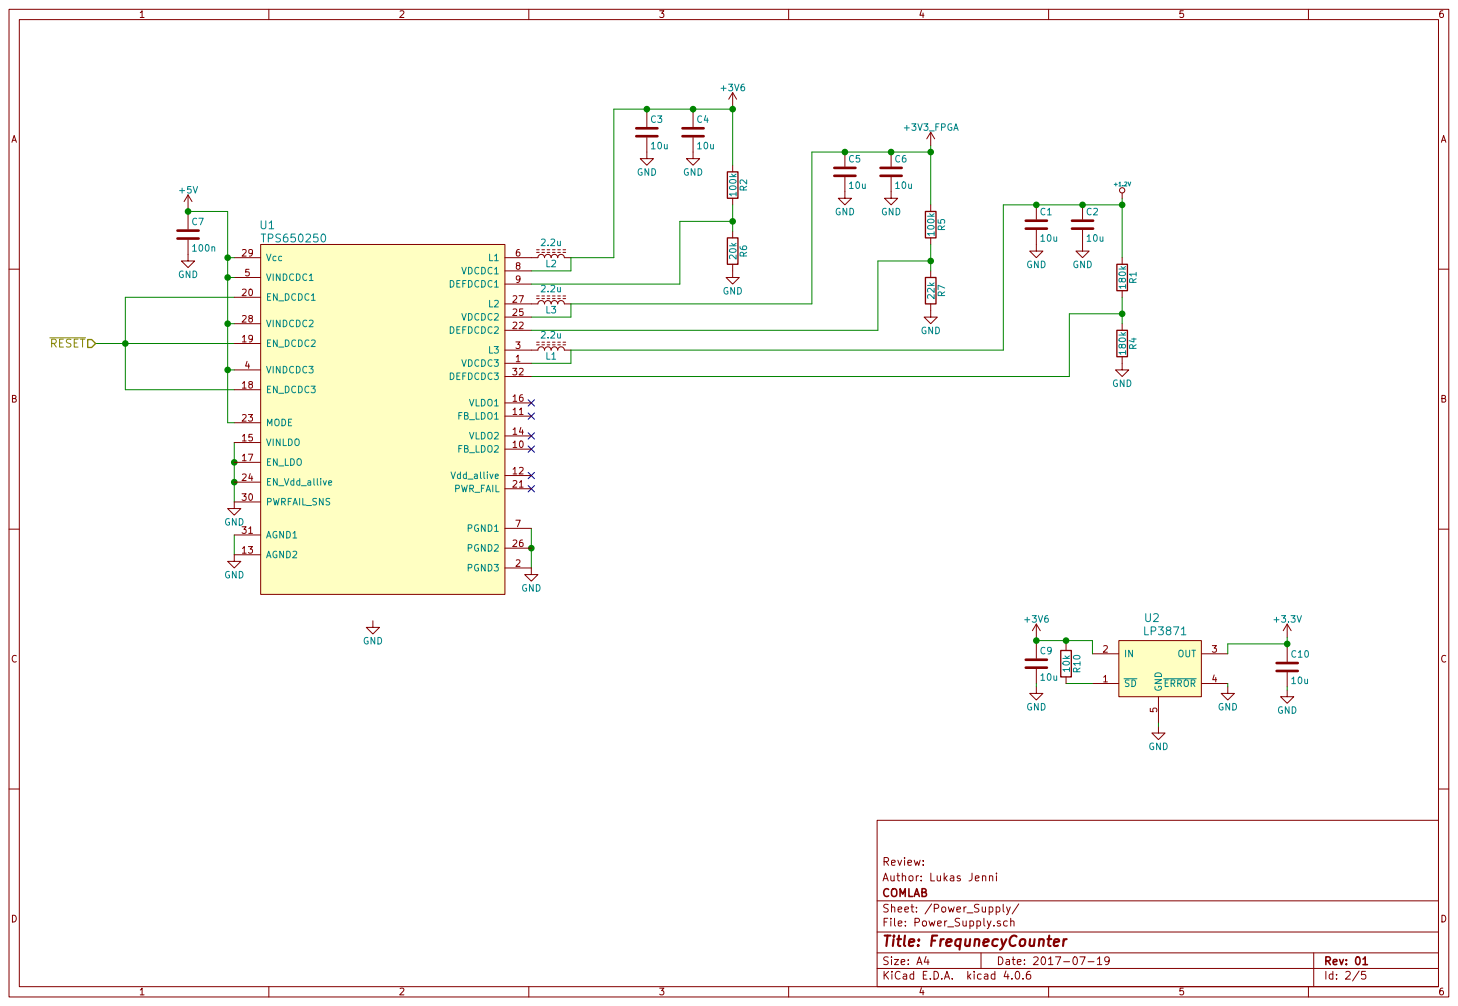
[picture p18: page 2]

Author: Lukas Jenni Review:

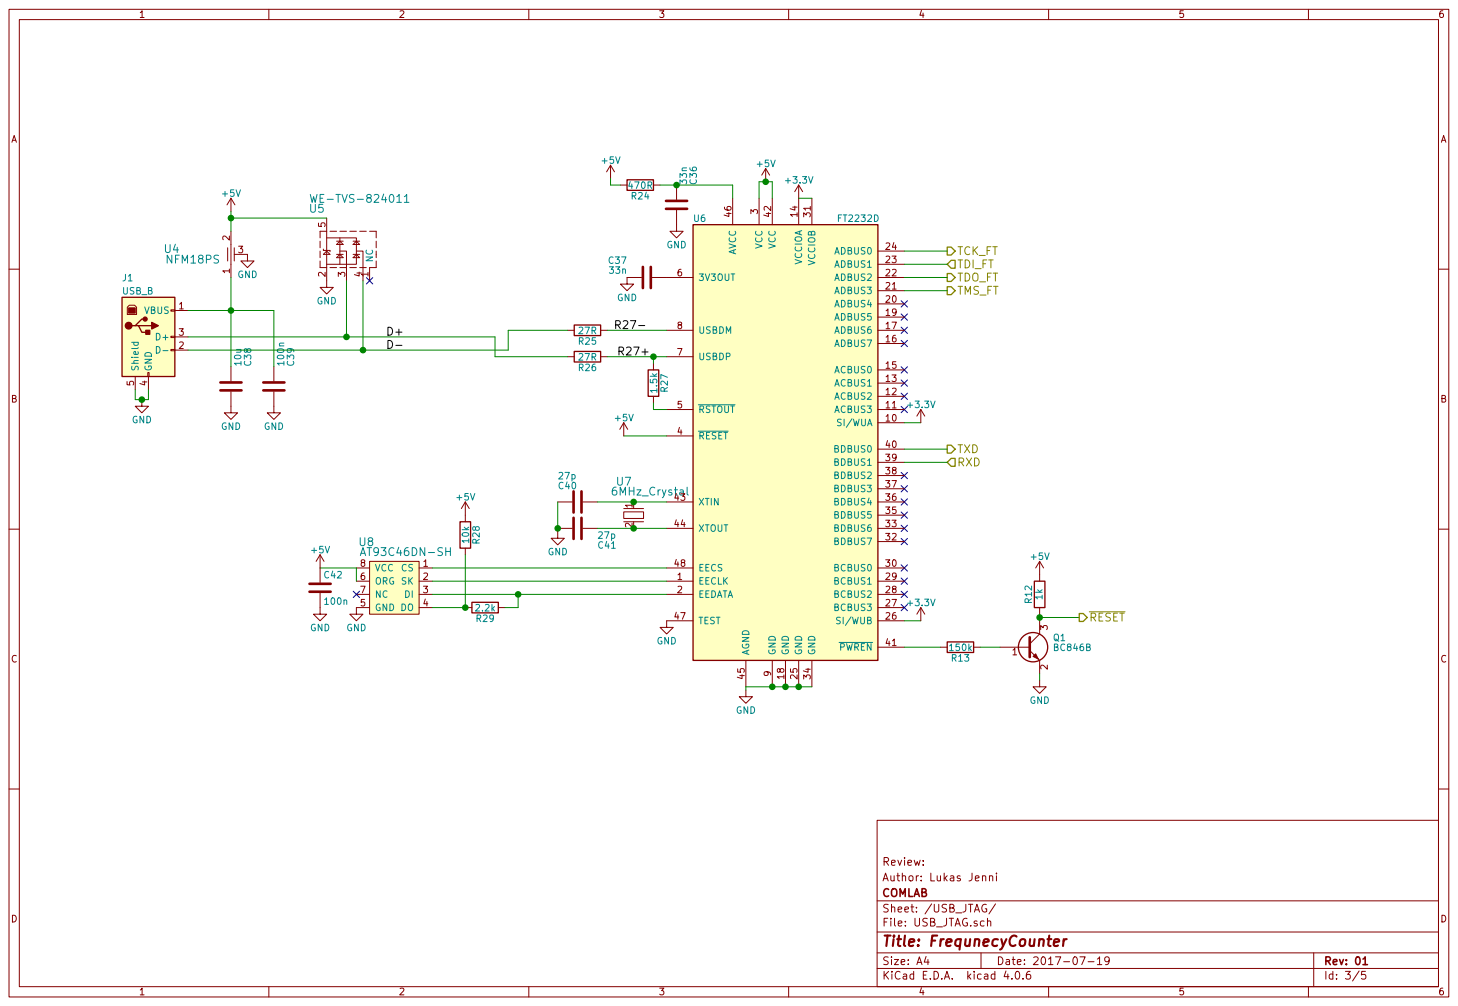
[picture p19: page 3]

9 SI/WUA 10 ADBUS4 20 BCBUS0 30 BDBUS0 40 ACBUS3 11 ADBUS3 21 VCCIOB 31 PWREN 41 ACBUS2 12 ADBUS2 22 BDBUS7 32 VCC 42 ACBUS1 13 ADBUS1 23 BDBUS6 33 XTIN 43 VCCIOA 14 ADBUS0 24 GND 34 XTOUT 44 ACBUS0 15 GND 25 BDBUS5 35 AGND 45 ADBUS7 16 SI/WUB 26 BDBUS4 36 AVCC 46 ADBUS6 17 BCBUS3 27 BDBUS3 37 TEST 47 GND 18 BCBUS2 28 BDBUS2 38 EECS 48 ADBUS5 19 BCBUS1 29 BDBUS1 39 U6 FT2232D 33n C36 100n C39 GND TCK_FT

Author: Lukas Jenni Review:

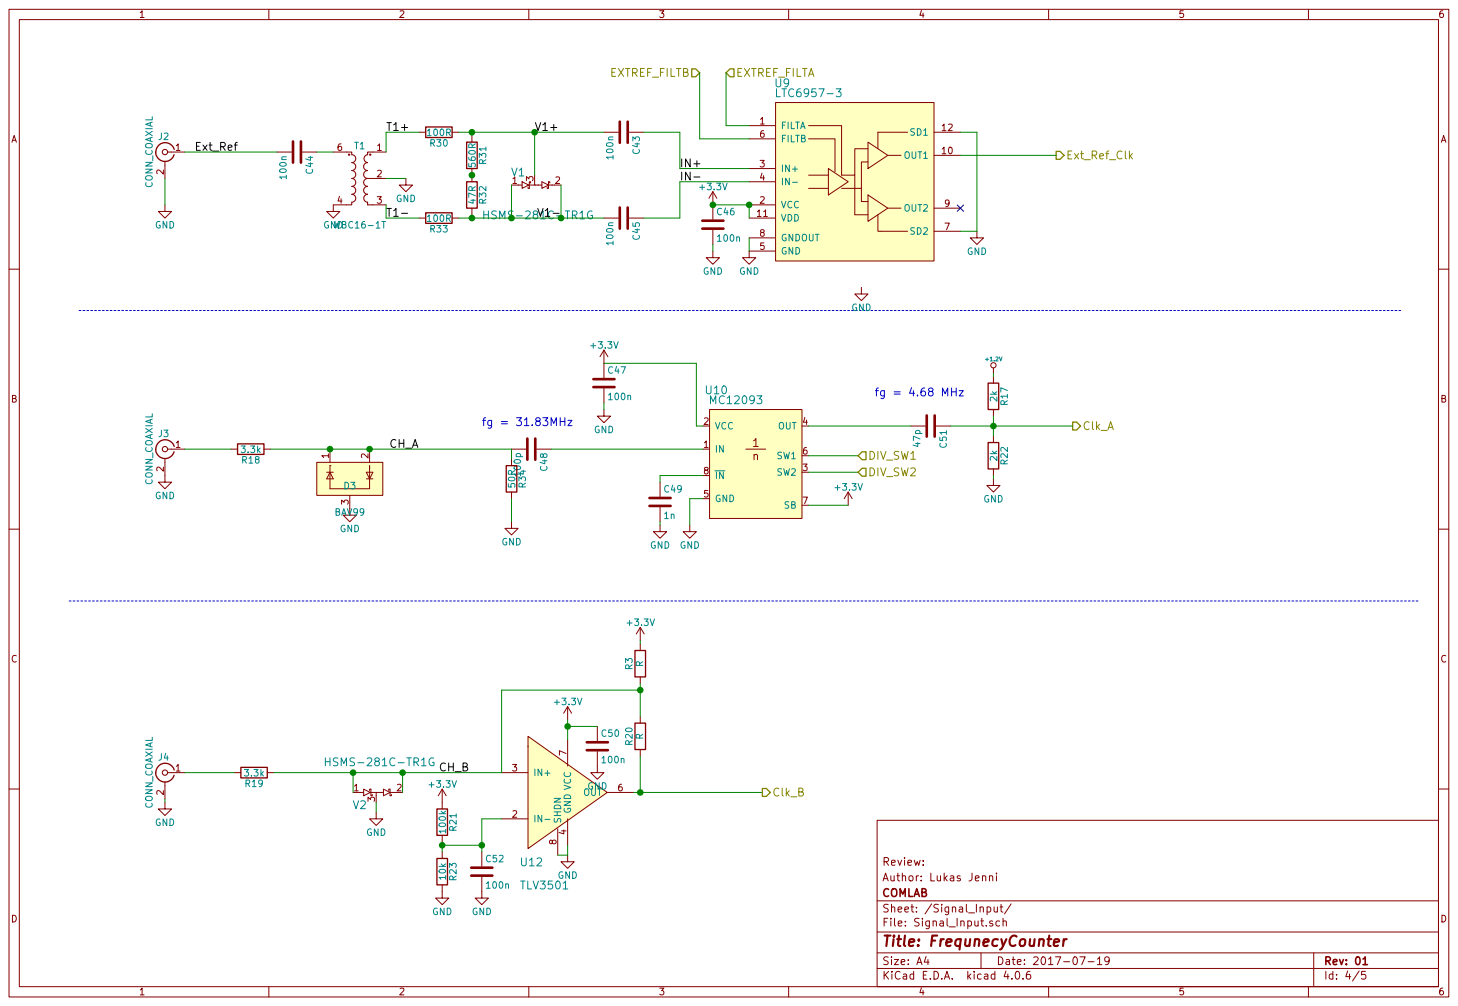
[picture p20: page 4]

Author: Lukas Jenni Review:

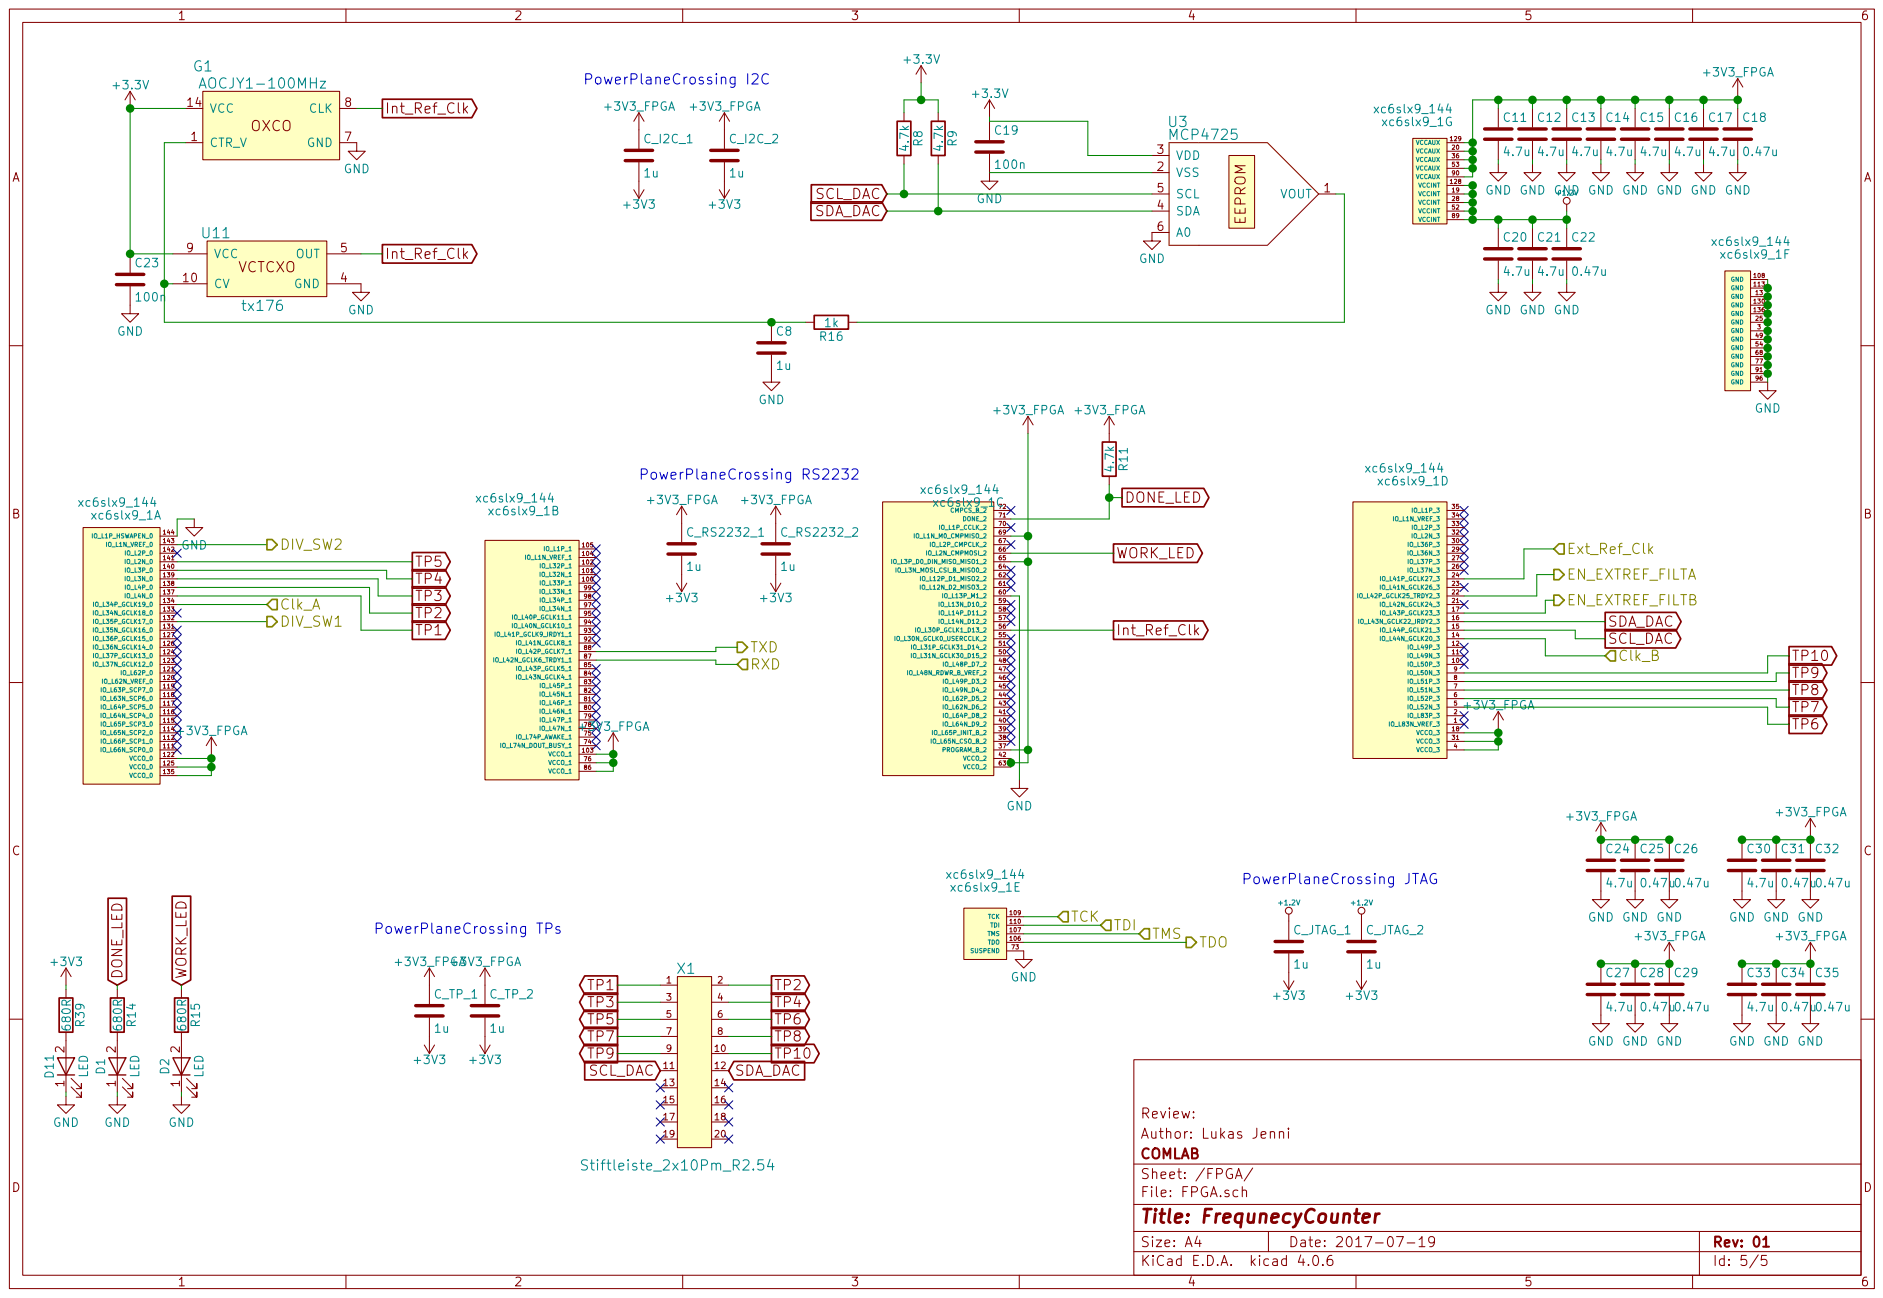
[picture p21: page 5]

4.7u GND GND GND GND GND

Author: Lukas Jenni Review:

Id: 5/5 Title: FrequnecyCounter File: FPGA.sch Sheet: /FPGA/ COMLAB

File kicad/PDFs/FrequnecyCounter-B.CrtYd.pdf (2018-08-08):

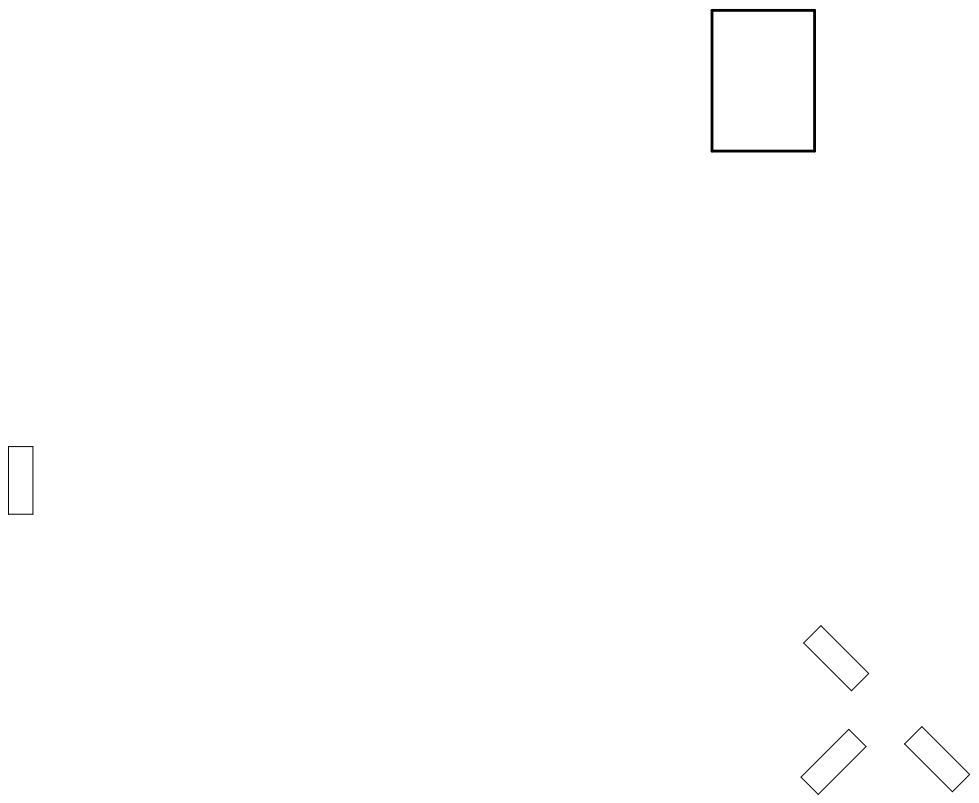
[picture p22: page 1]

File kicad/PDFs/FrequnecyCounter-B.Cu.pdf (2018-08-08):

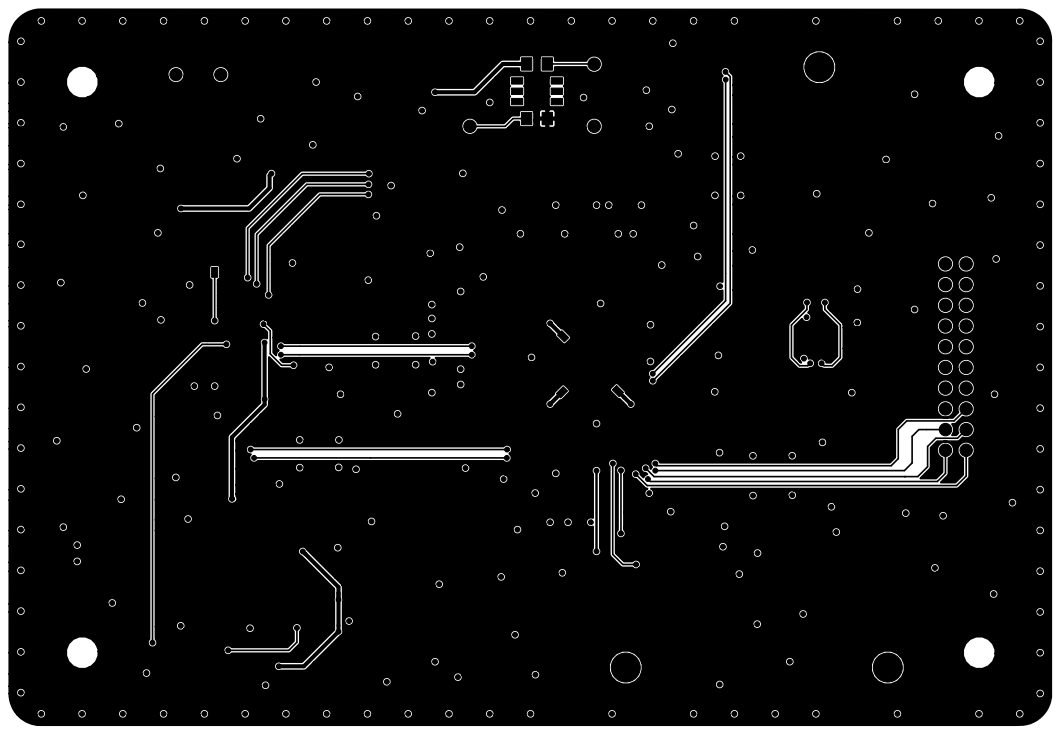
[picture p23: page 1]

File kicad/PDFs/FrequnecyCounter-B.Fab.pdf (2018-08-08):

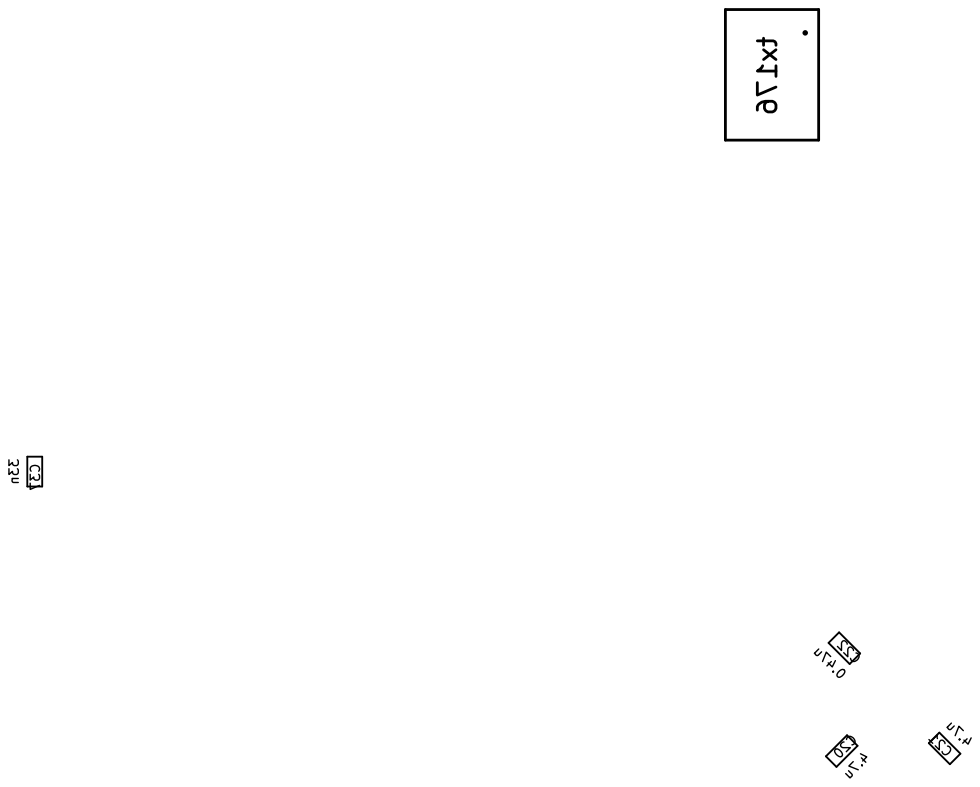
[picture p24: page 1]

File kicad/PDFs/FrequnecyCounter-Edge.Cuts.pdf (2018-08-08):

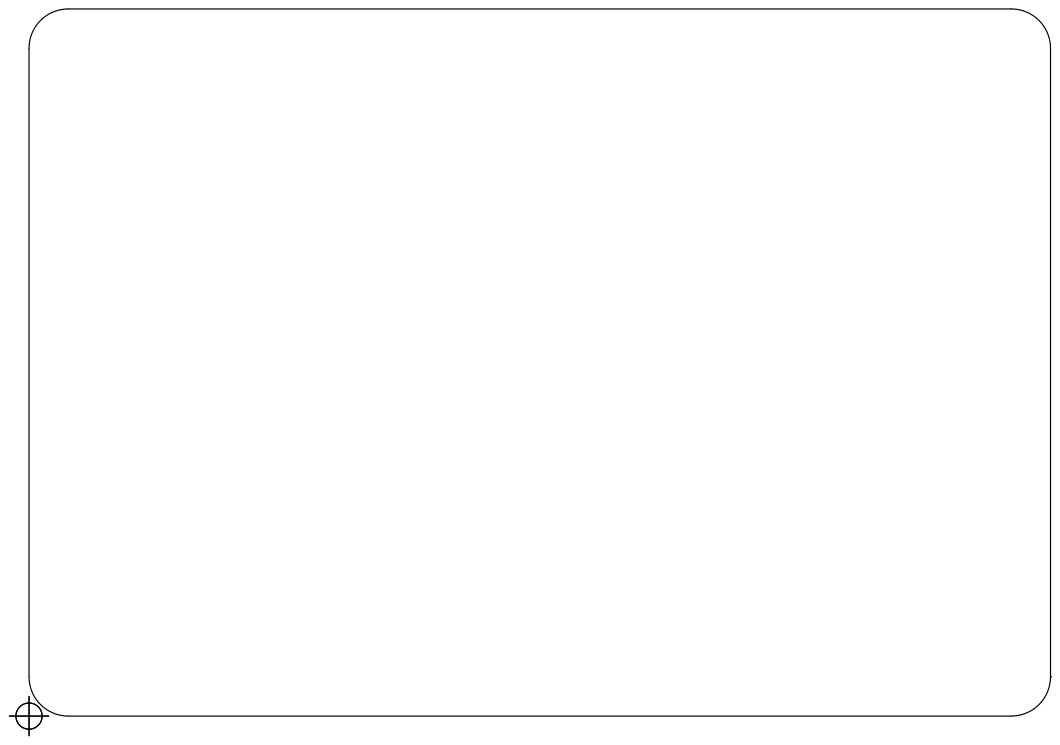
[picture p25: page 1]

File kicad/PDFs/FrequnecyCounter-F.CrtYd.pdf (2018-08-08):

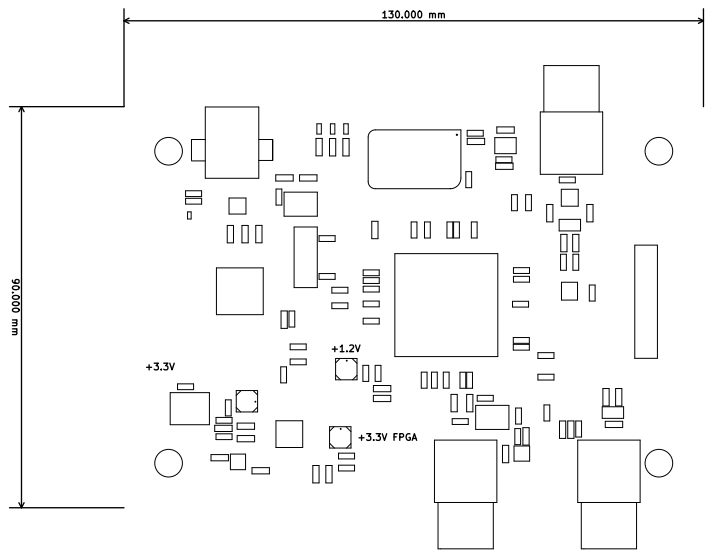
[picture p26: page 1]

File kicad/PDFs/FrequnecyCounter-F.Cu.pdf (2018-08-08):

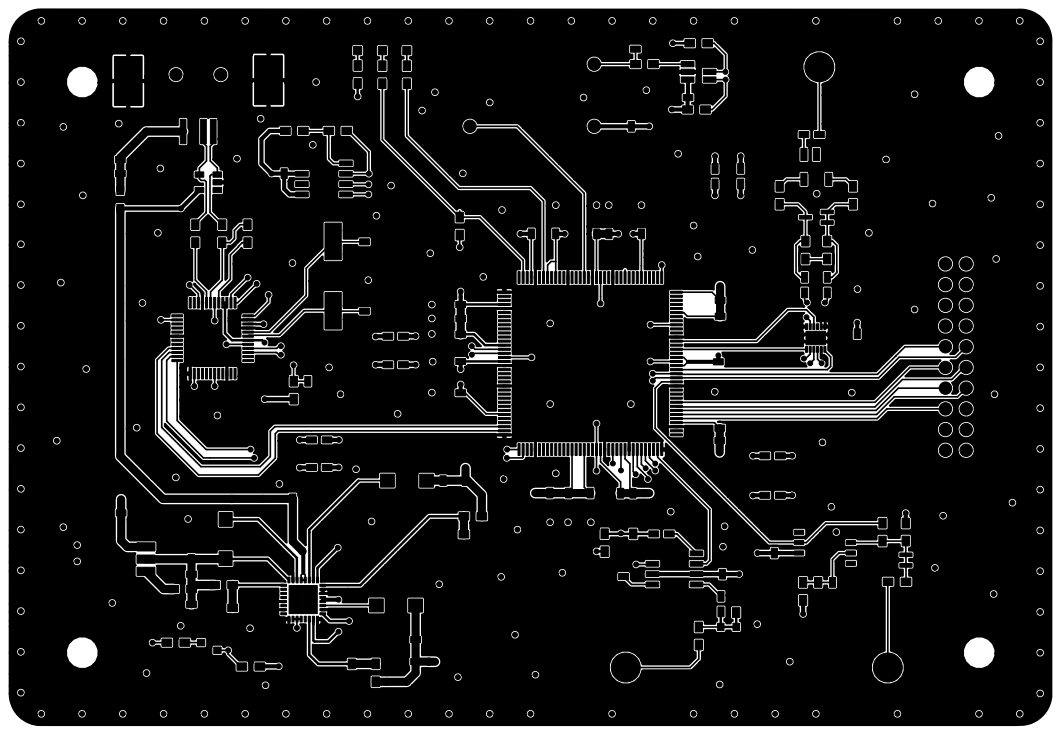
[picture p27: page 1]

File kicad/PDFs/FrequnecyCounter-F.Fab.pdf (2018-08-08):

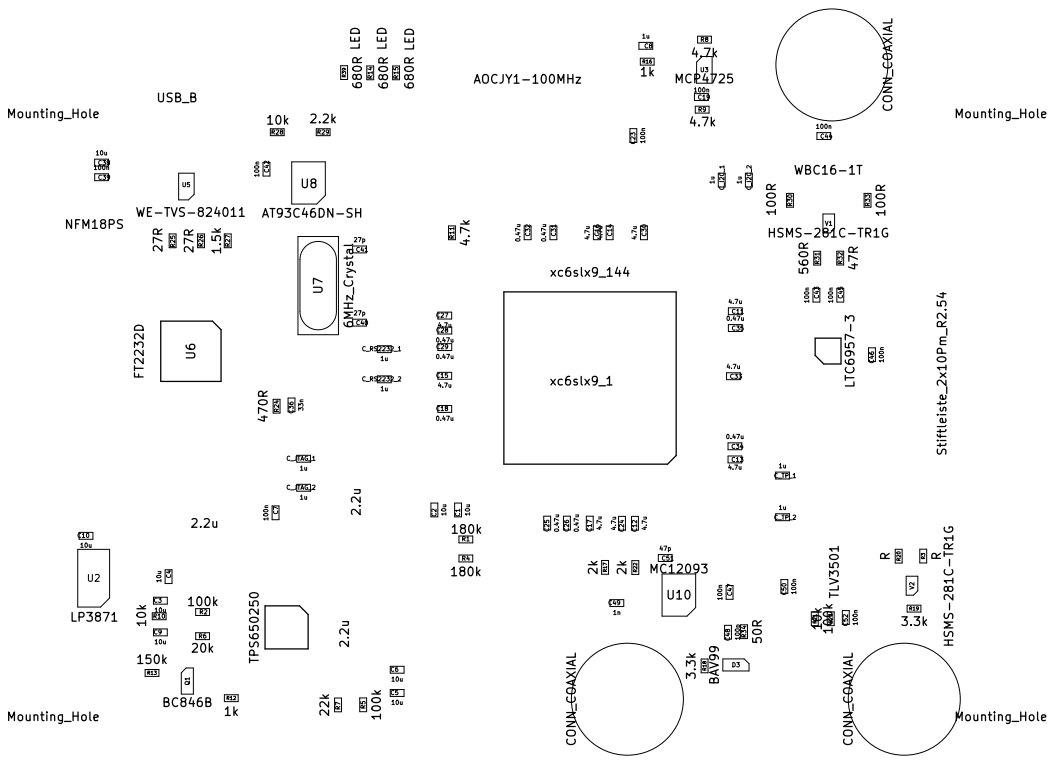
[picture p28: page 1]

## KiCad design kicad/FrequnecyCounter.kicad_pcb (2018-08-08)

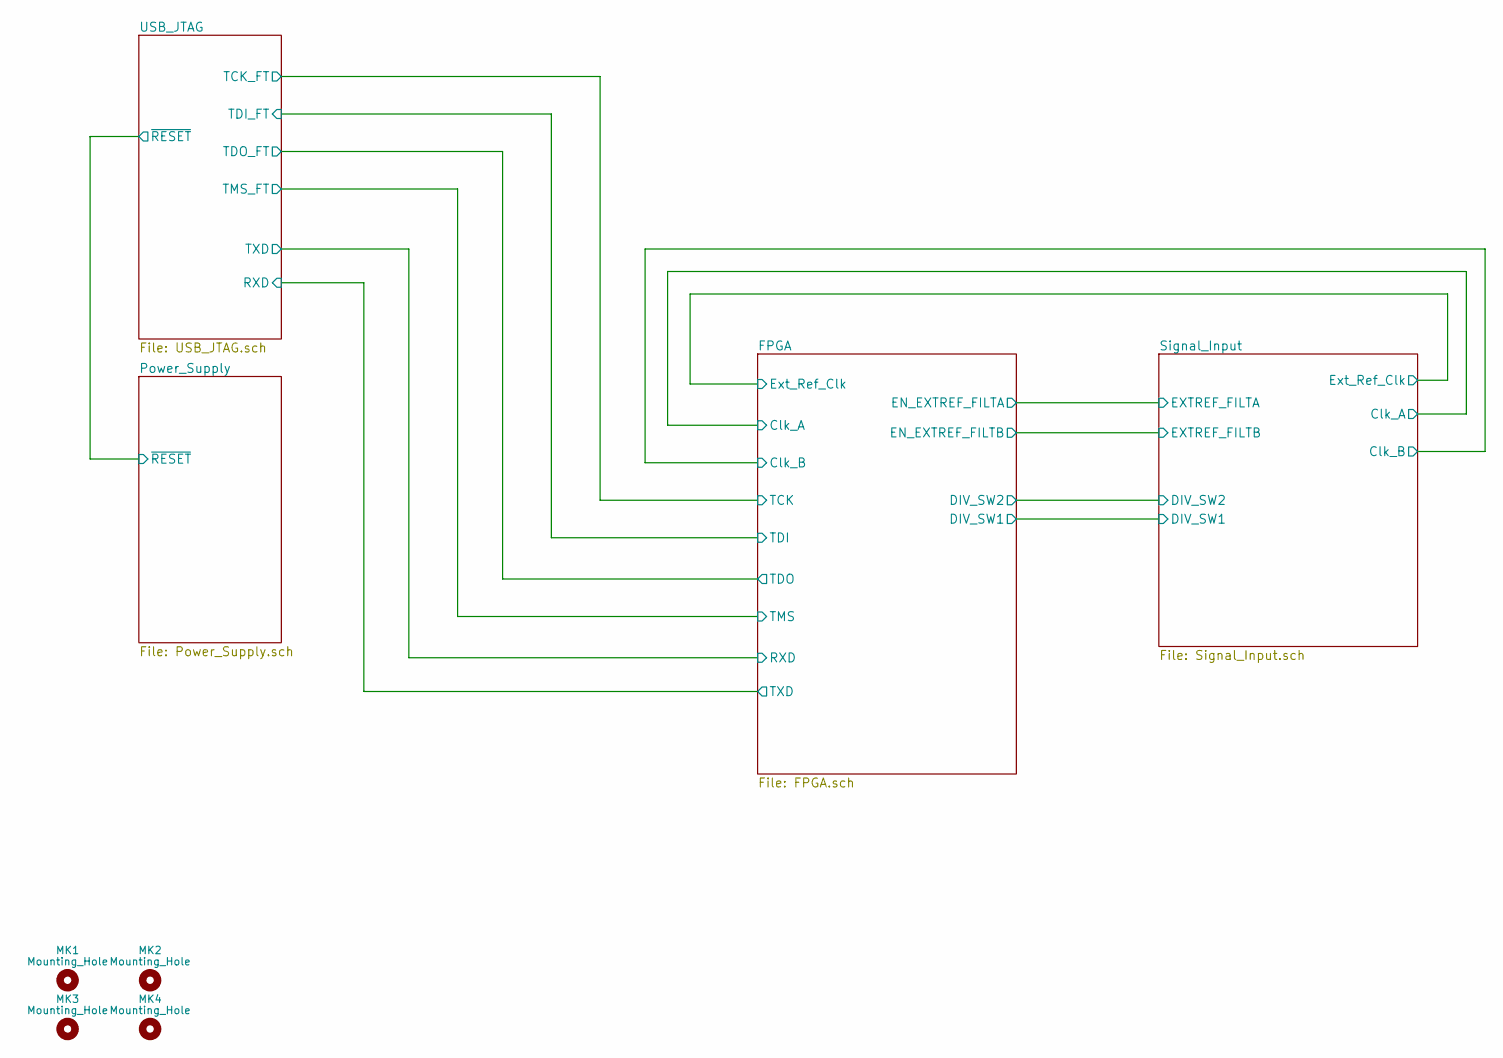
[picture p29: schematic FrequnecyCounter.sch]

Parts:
MK1, MK2, MK3, MK4: Mounting_Hole; MountingHole_3.2mm_M3_ISO7380

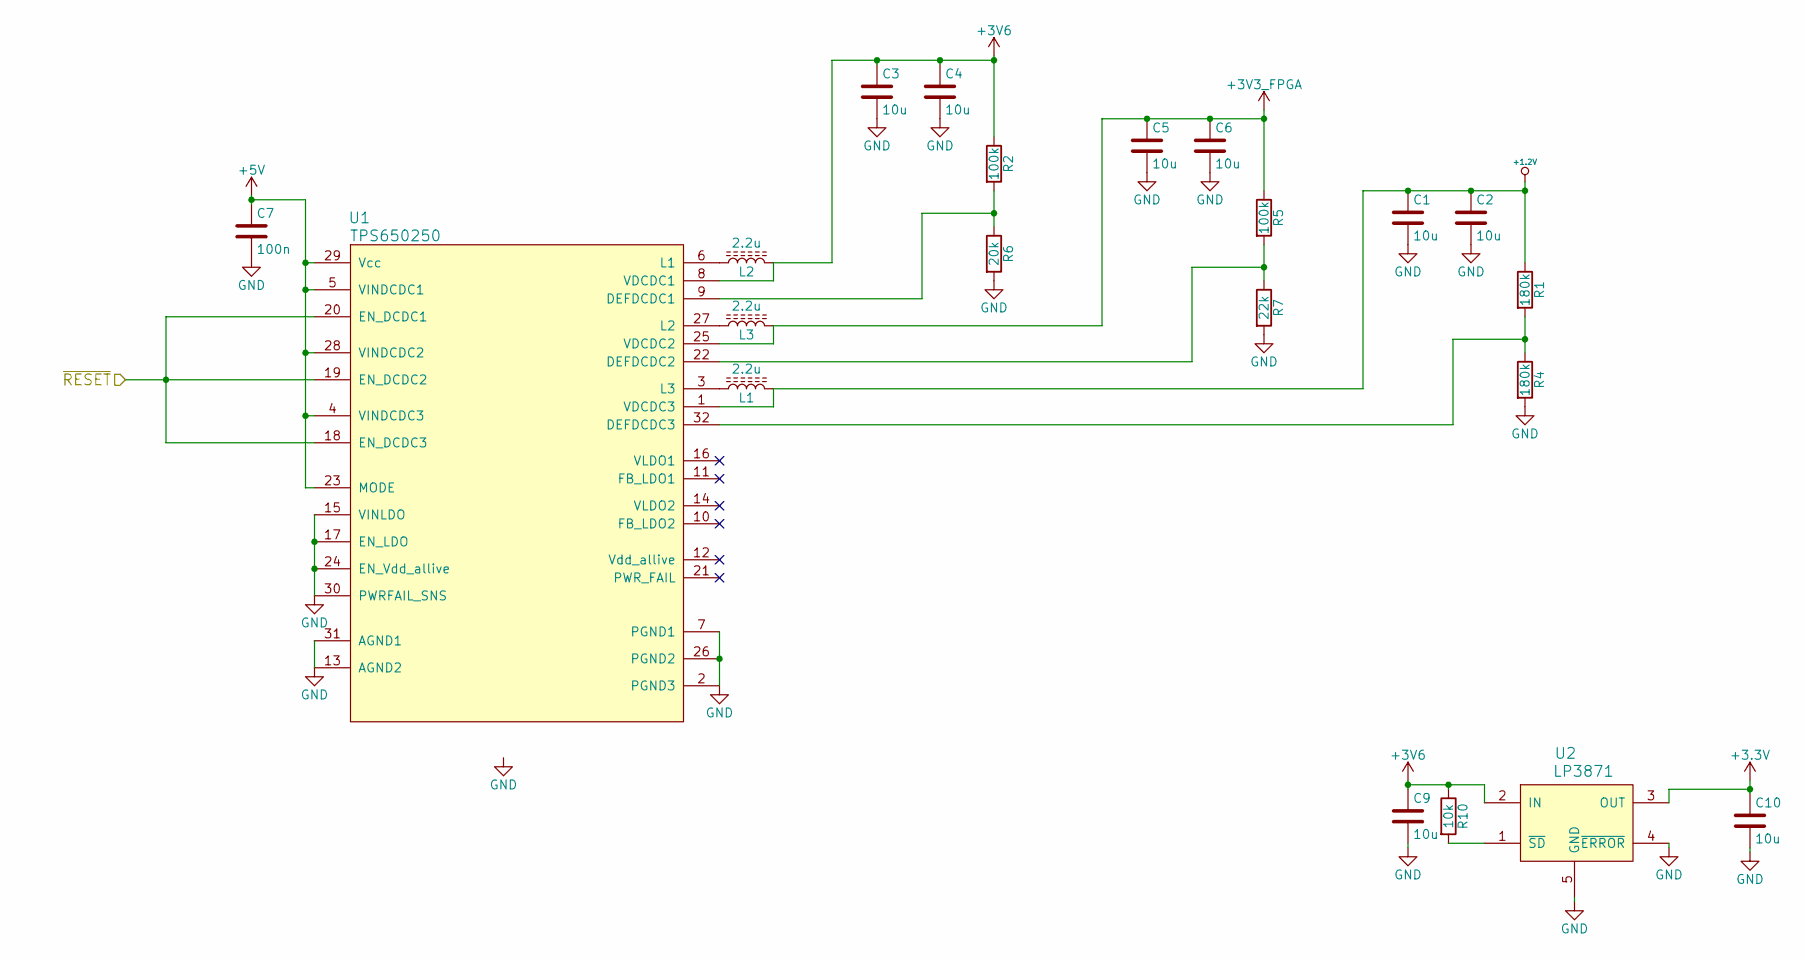
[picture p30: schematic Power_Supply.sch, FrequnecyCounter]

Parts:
C1, C2, C3, C4, C5, C6, C9, C10: 10u; Cap_0603_HandSoldering_1
C7: 100n; Cap_0603_HandSoldering_1
L1, L2, L3: 2.2u; LPS5030
R1, R4: 180k; R_0603_HandSoldering
R2, R5: 100k; R_0603_HandSoldering
R6: 20k; R_0603_HandSoldering
R7: 22k; R_0603_HandSoldering
R10: 10k; R_0603_HandSoldering
U1: TPS650250; QFN-32-1EP_5x5mm_Pitch0.5mm
U2: LP3871; SOT-223-5

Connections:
+1.2V: C1.1, C2.1, L1.2, R1.1, U1.1 (VDCDC3); also elsewhere on the board
+3V3_FPGA: C5.1, C6.1, L3.2, R5.1, U1.25 (VDCDC2); also elsewhere on the board
+3V6: C3.1, C4.1, C9.1, L2.2, R2.1, R10.1, U1.8 (VDCDC1), U2.2 (IN)
+5V: C7.1, U1.4 (VINDCDC3), U1.5 (VINDCDC1), U1.23 (MODE), U1.28 (VINDCDC2), U1.29 (Vcc); also elsewhere on the board
/Power_Supply/~RESET: U1.18 (EN_DCDC3), U1.19 (EN_DCDC2), U1.20 (EN_DCDC1); also elsewhere on the board
GND: C1.2, C2.2, C3.2, C4.2, C5.2, C6.2, C7.2, C9.2, C10.2, R4.2, R6.2, R7.2, U1.2 (PGND3), U1.7 (PGND1), U1.13 (AGND2), U1.15 (VINLDO), U1.17 (EN_LDO), U1.24 (EN_Vdd_allive), U1.26 (PGND2), U1.30 (PWRFAIL_SNS), U1.31 (AGND1), U1.33 (GND_PANEL), U2.4 (~ERROR), U2.5 (GND); also elsewhere on the board
unnamed: L1.1, U1.3 (L3)
unnamed: L2.1, U1.6 (L1)
unnamed: L3.1, U1.27 (L2)
unnamed: R1.2, R4.1, U1.32 (DEFDCDC3)
unnamed: R2.2, R6.1, U1.9 (DEFDCDC1)
unnamed: R5.2, R7.1, U1.22 (DEFDCDC2)
unnamed: R10.2, U2.1 (~SD)

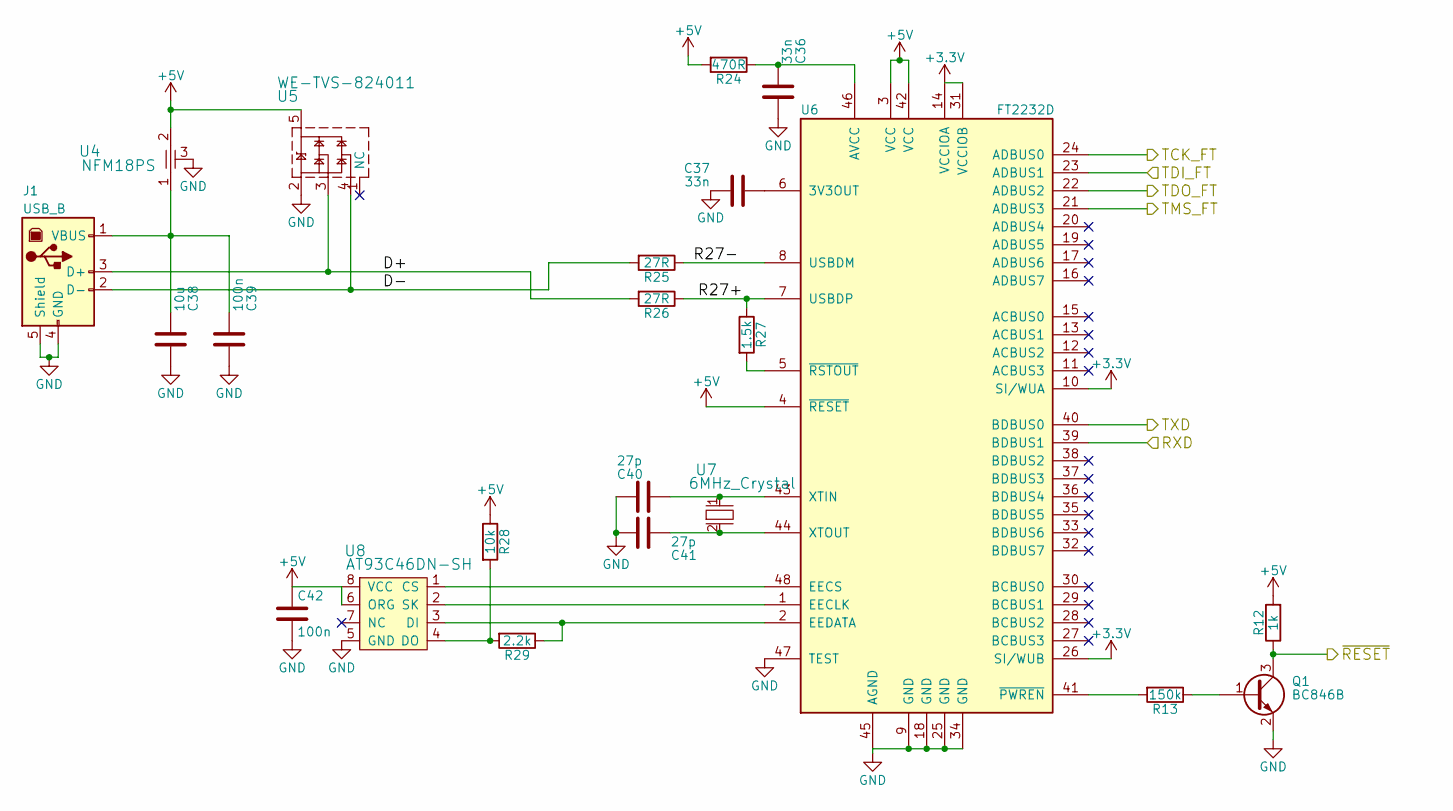
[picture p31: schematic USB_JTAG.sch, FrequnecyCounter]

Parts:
C36, C37: 33n; Cap_0603_HandSoldering_1
C38: 10u; Cap_0603_HandSoldering_1
C39, C42: 100n; Cap_0603_HandSoldering_1
C40, C41: 27p; Cap_0603_HandSoldering_1
J1: USB_B; USB_B_liegen_SMD
Q1: BC846B; SOT-23
R12: 1k; R_0603_HandSoldering
R13: 150k; R_0603_HandSoldering
R24: 470R; R_0603_HandSoldering
R25, R26: 27R; R_0603_HandSoldering
R27: 1.5k; R_0603_HandSoldering
R28: 10k; R_0603_HandSoldering
R29: 2.2k; R_0603_HandSoldering
U4: NFM18PS
U5: WE-TVS-824011; SOT-23-5
U6: FT2232D; LQFP-48_7x7mm_Pitch0.5mm
U7: 6MHz_Crystal; Crystal_SMD_HC49-SD
U8: AT93C46DN-SH; SOIC-8_3.9x4.9mm_Pitch1.27mm

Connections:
+5V: C42.1, R12.2, R24.2, R28.1, U4.2, U5.5, U6.3 (VCC), U6.4 (~RESET), U6.42 (VCC), U8.6 (ORG), U8.8 (VCC); also elsewhere on the board
/FPGA/RXD: U6.40 (BDBUS0); also elsewhere on the board
/FPGA/TCK: U6.24 (ADBUS0); also elsewhere on the board
/FPGA/TDI: U6.23 (ADBUS1); also elsewhere on the board
/FPGA/TDO: U6.22 (ADBUS2); also elsewhere on the board
/FPGA/TMS: U6.21 (ADBUS3); also elsewhere on the board
/Power_Supply/~RESET: Q1.3 (C), R12.1; also elsewhere on the board
/USB_JTAG/D+: J1.3 (D+), R26.2, U5.3
/USB_JTAG/D-: J1.2 (D-), R25.2, U5.4
/USB_JTAG/R27+: R26.1, R27.1, U6.7 (USBDP)
/USB_JTAG/R27-: R25.1, U6.8 (USBDM)
/USB_JTAG/RXD: U6.39 (BDBUS1); also elsewhere on the board
GND: C36.2, C37.1, C38.2, C39.2, C40.2, C41.2, C42.2, J1.4 (GND), J1.5 (Shield), Q1.2 (E), U4.3, U5.2, U6.9 (GND), U6.18 (GND), U6.25 (GND), U6.34 (GND), U6.45 (AGND), U6.47 (TEST), U8.5 (GND); also elsewhere on the board
unnamed: C36.1, R24.1, U6.46 (AVCC)
unnamed: C37.2, U6.6 (3V3OUT)
unnamed: C38.1, C39.1, J1.1 (VBUS), U4.1
unnamed: C40.1, U6.43 (XTIN), U7.1
unnamed: C41.1, U6.44 (XTOUT), U7.2
unnamed: Q1.1 (B), R13.1
unnamed: R13.2, U6.41 (~PWREN)
unnamed: R27.2, U6.5 (~RSTOUT)
unnamed: R28.2, R29.2, U8.4 (DO)
unnamed: R29.1, U6.2 (EEDATA), U8.3 (DI)
unnamed: U6.1 (EECLK), U8.2 (SK)
unnamed: U6.48 (EECS), U8.1 (CS)

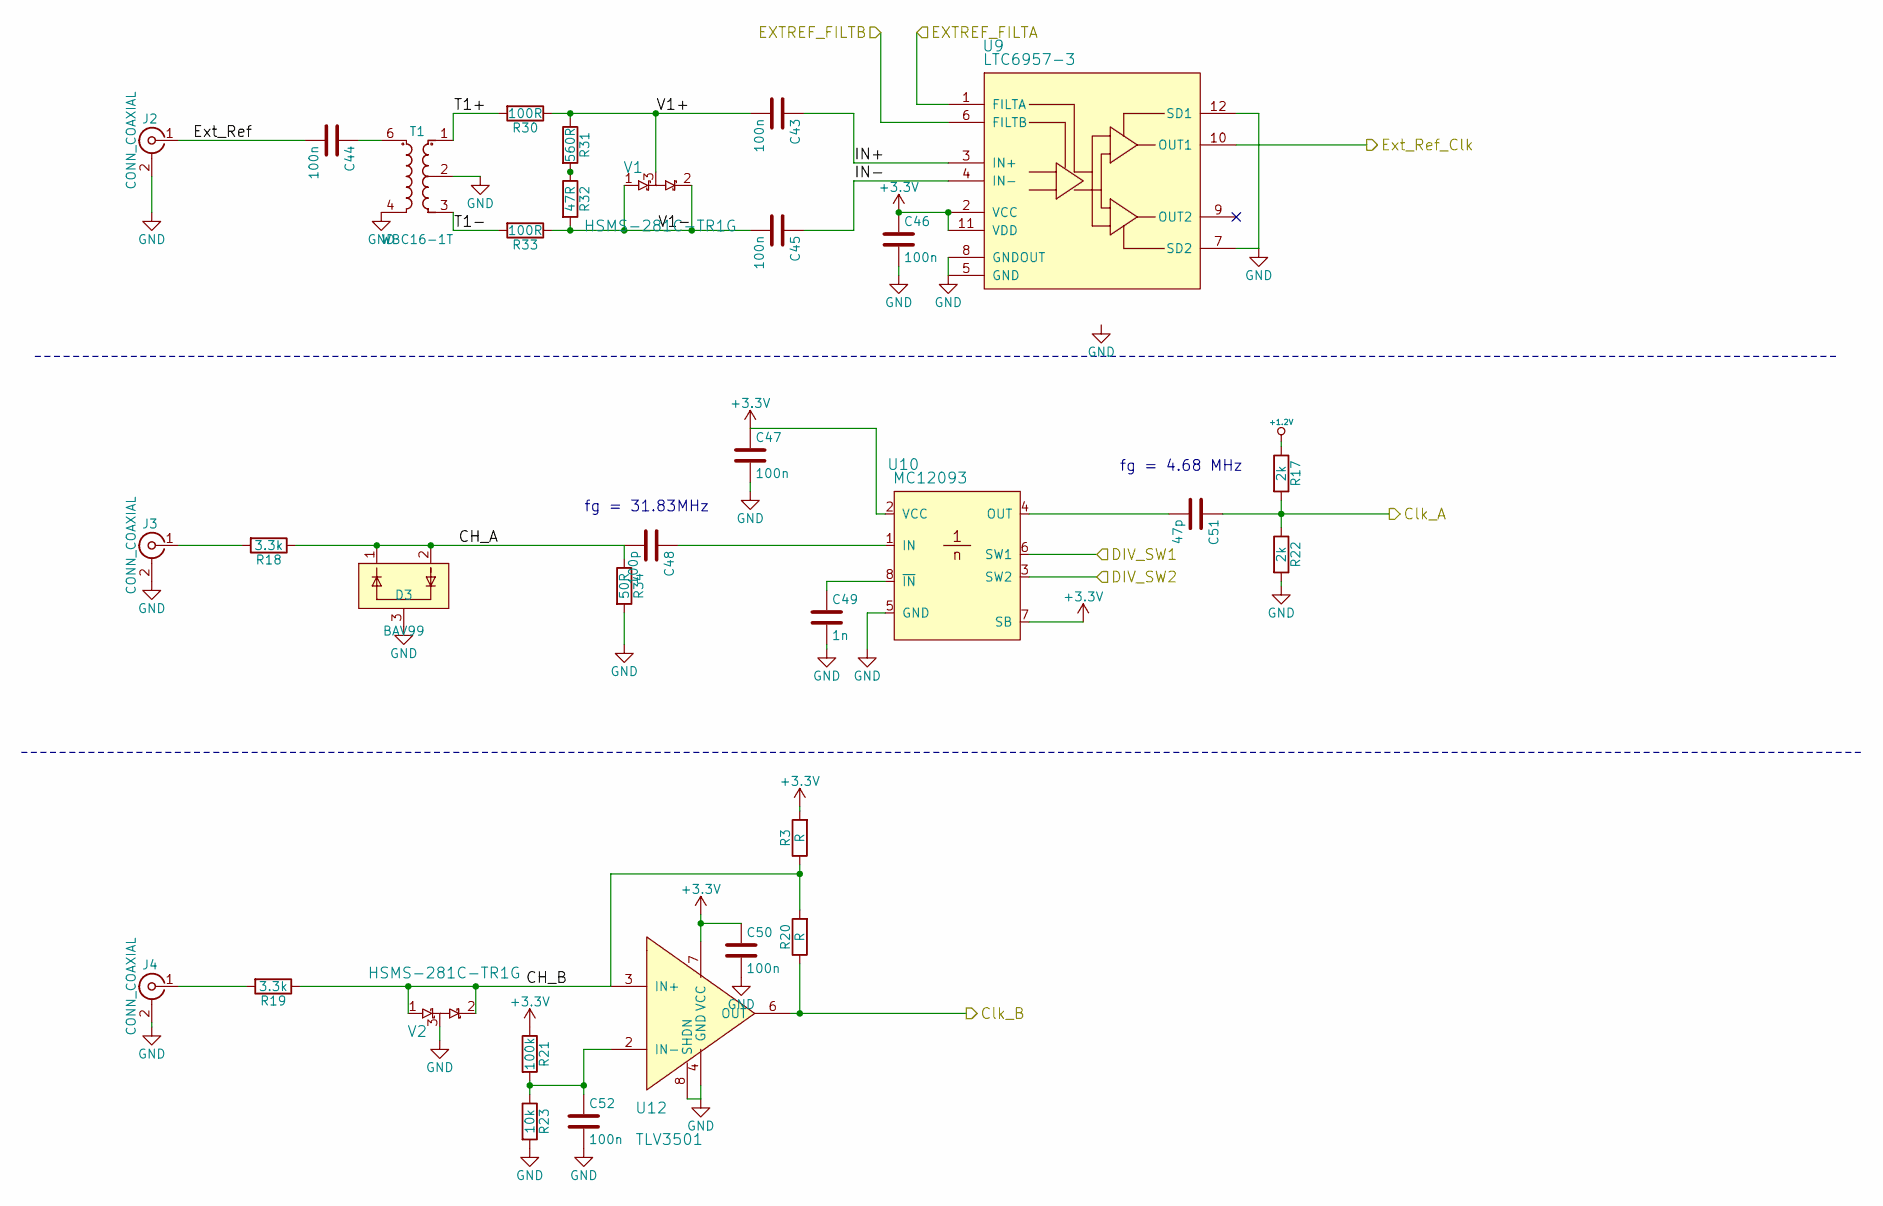
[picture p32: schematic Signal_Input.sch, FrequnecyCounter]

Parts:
C43, C44, C45, C46, C47, C50, C52: 100n; Cap_0603_HandSoldering_1
C48: 100p; Cap_0603_HandSoldering_1
C49: 1n; Cap_0603_HandSoldering_1
C51: 47p; Cap_0603_HandSoldering_1
D3: BAV99; SOT-23
J2, J3, J4: CONN_COAXIAL; bncf-horizontal
R3, R20: R; R_0603_HandSoldering
R17, R22: 2k; R_0603_HandSoldering
R18, R19: 3.3k; R_0603_HandSoldering
R21: 100k; R_0603_HandSoldering
R23: 10k; R_0603_HandSoldering
R30, R33: 100R; R_0603_HandSoldering
R31: 560R; R_0603_HandSoldering
R32: 47R; R_0603_HandSoldering
R34: 50R; R_0603_HandSoldering
T1: WBC16-1T; wbc-16-1T
U9: LTC6957-3; DFN-12-1EP_3x3mm_Pitch0.45mm
U10: MC12093; SOIC-8_3.9x4.9mm_Pitch1.27mm
U12: TLV3501; SOIC-8-N
V1, V2: HSMS-281C-TR1G; SOT-323_SC-70_Handsoldering

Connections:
+1.2V: R17.1; also elsewhere on the board
/FPGA/Clk_A: C51.1, R17.2, R22.1; also elsewhere on the board
/FPGA/Clk_B: R20.1, U12.6 (OUT); also elsewhere on the board
/FPGA/DIV_SW1: U10.6 (SW1); also elsewhere on the board
/FPGA/DIV_SW2: U10.3 (SW2); also elsewhere on the board
/FPGA/EN_EXTREF_FILTA: U9.1 (FILTA); also elsewhere on the board
/FPGA/EN_EXTREF_FILTB: U9.6 (FILTB); also elsewhere on the board
/FPGA/Ext_Ref_Clk: U9.10 (OUT1); also elsewhere on the board
/Signal_Input/CH_A: C48.2, D3.1, D3.2, R18.1, R34.1
/Signal_Input/CH_B: R3.1, R19.1, R20.2, U12.3 (IN+), V2.1, V2.2
/Signal_Input/Ext_Ref: C44.2, J2.1 (In)
/Signal_Input/IN+: C43.1, U9.3 (IN+)
/Signal_Input/IN-: C45.1, U9.4 (IN-)
/Signal_Input/T1+: R30.2, T1.1
/Signal_Input/T1-: R33.2, T1.3
/Signal_Input/V1+: C43.2, R30.1, R31.1, V1.3
/Signal_Input/V1-: C45.2, R32.2, R33.1, V1.1, V1.2
GND: C46.2, C47.2, C49.2, C50.2, C52.2, D3.3, J2.2 (Ext), J3.2 (Ext), J4.2 (Ext), R22.2, R23.2, R34.2, T1.2, T1.4, U9.5 (GND), U9.7 (SD2), U9.8 (GNDOUT), U9.12 (SD1), U9.13 (GND_Panel), U10.5 (GND), U12.4 (GND), U12.8 (SHDN), V2.3; also elsewhere on the board
unnamed: C44.1, T1.6
unnamed: C48.1, U10.1 (IN)
unnamed: C49.1, U10.8 (~IN)
unnamed: C51.2, U10.4 (OUT)
unnamed: C52.1, R21.2, R23.1, U12.2 (IN-)
unnamed: J3.1 (In), R18.2
unnamed: J4.1 (In), R19.2
unnamed: R31.2, R32.1

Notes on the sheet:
fg = 4.68 MHz
fg = 31.83MHz

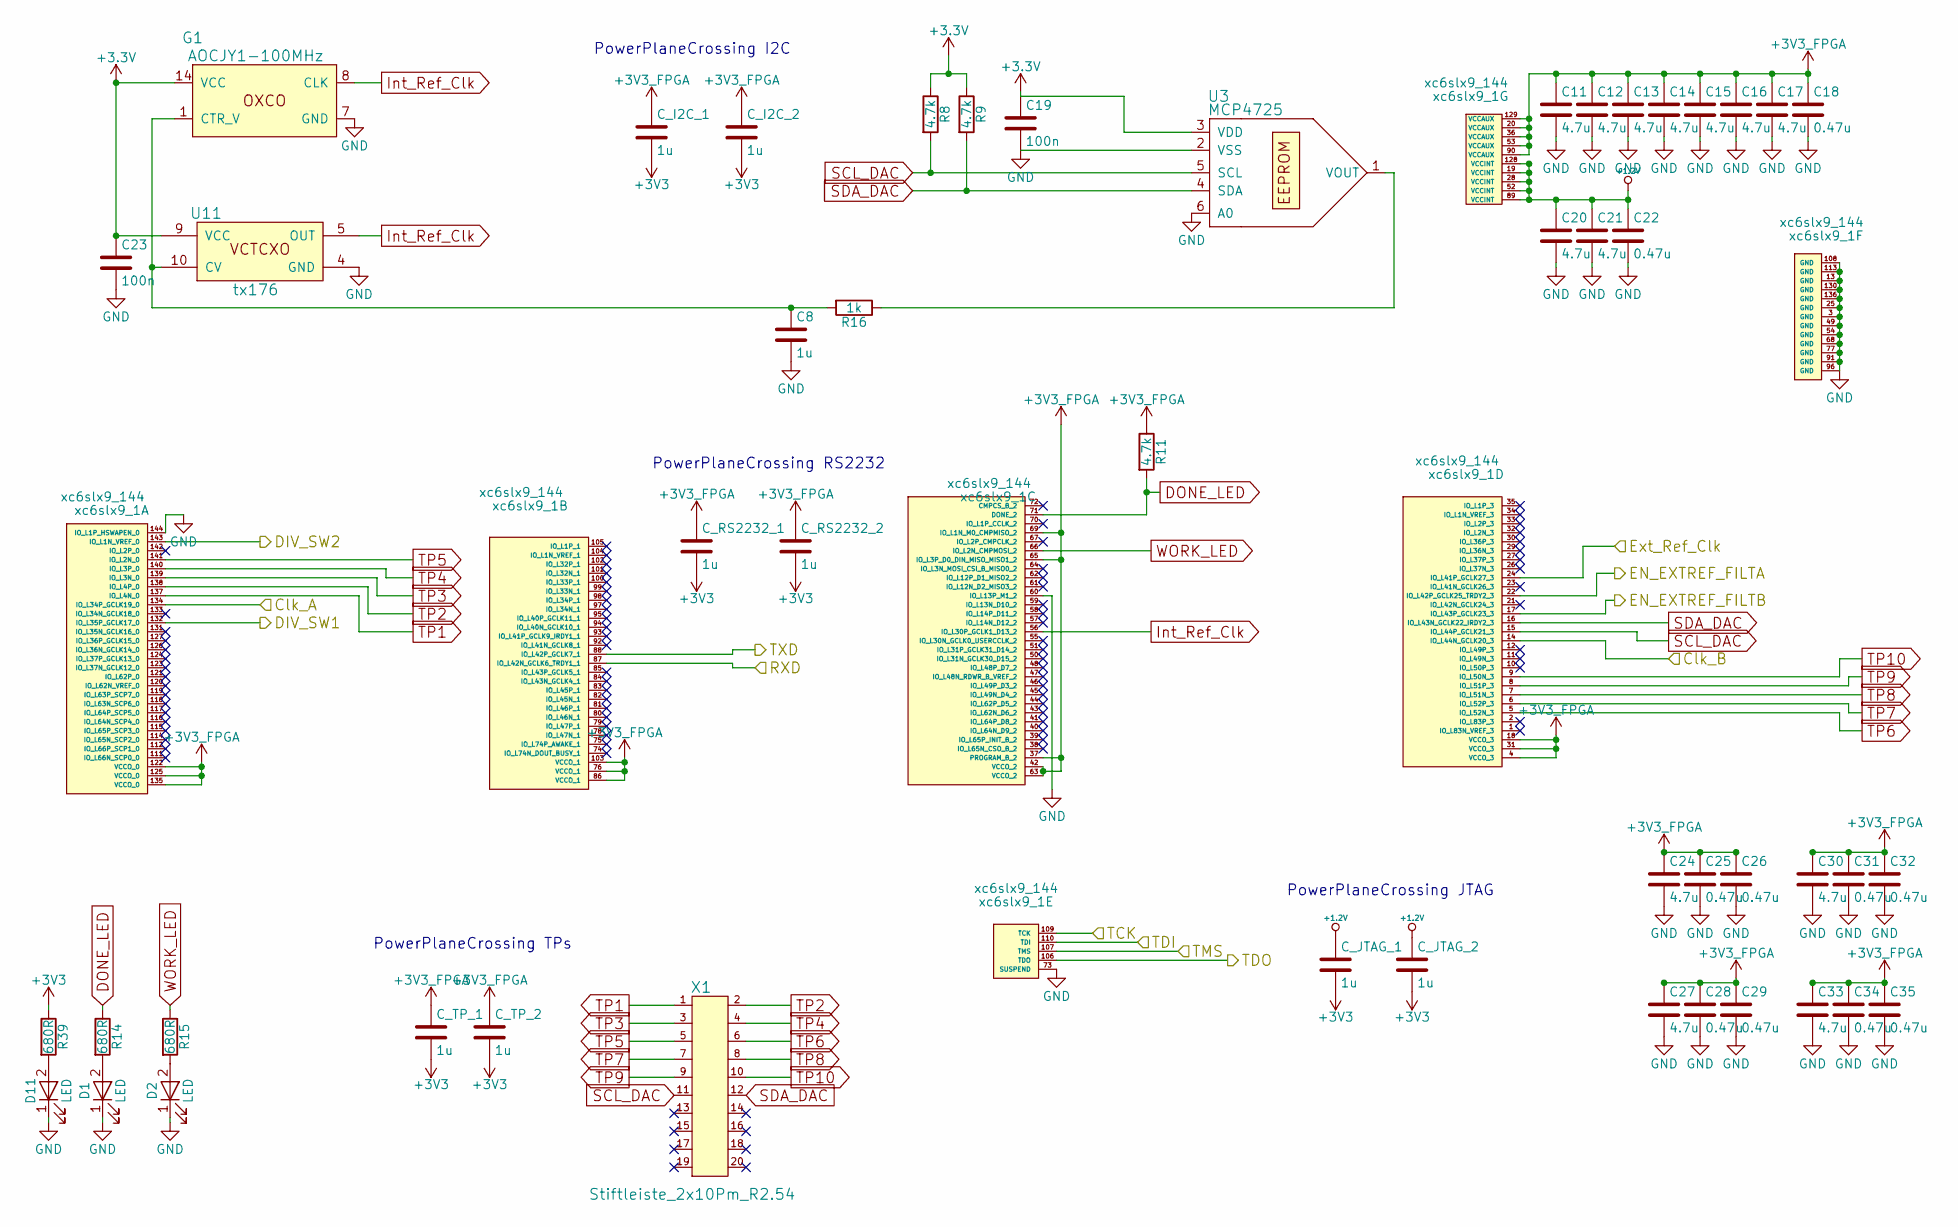
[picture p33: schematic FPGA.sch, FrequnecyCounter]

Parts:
C8: 1u; Cap_0603_HandSoldering_1
C11, C12, C13, C14, C15, C16, C17, C20, C21, C24, C27, C30, C33: 4.7u; Cap_0603_HandSoldering_1
C18, C22, C25, C26, C28, C29, C31, C32, C34, C35: 0.47u; Cap_0603_HandSoldering_1
C19, C23: 100n; Cap_0603_HandSoldering_1
C_I2C_1, C_I2C_2: 1u; Cap_0603_HandSoldering_1
C_JTAG_1, C_JTAG_2: 1u; Cap_0603_HandSoldering_1
C_RS2232_1, C_RS2232_2: 1u; Cap_0603_HandSoldering_1
C_TP_1, C_TP_2: 1u; Cap_0603_HandSoldering_1
D1, D2, D11: LED; Mini_TopLed_SMD
G1: AOCJY1-100MHz; Crystal_smd_4pin_20.8x13.2
R8, R9, R11: 4.7k; R_0603_HandSoldering
R14, R15, R39: 680R; R_0603_HandSoldering
R16: 1k; R_0603_HandSoldering
U3: MCP4725; SOT-23-6_Handsoldering
U11: tx176
X1: Stiftleiste_2x10Pm_R2.54
xc6slx9_1: xc6slx9_144; TQFP-144_20x20mm_Pitch0.5mm

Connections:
+1.2V: C20.1, C21.1, C22.1, C_JTAG_1.1, C_JTAG_2.1, xc6slx9_1.19 (VCCINT), xc6slx9_1.28 (VCCINT), xc6slx9_1.52 (VCCINT), xc6slx9_1.89 (VCCINT), xc6slx9_1.128 (VCCINT); also elsewhere on the board
+3V3_FPGA: C11.1, C12.1, C13.1, C14.1, C15.1, C16.1, C17.1, C18.1, C24.1, C25.1, C26.1, C27.1, C28.1, C29.1, C30.1, C31.1, C32.1, C33.1, C34.1, C35.1, C_I2C_1.1, C_I2C_2.1, C_RS2232_1.1, C_RS2232_2.1, C_TP_1.1, C_TP_2.1, R11.1, xc6slx9_1.4 (VCCO_3), xc6slx9_1.18 (VCCO_3), xc6slx9_1.20 (VCCAUX), xc6slx9_1.31 (VCCO_3), xc6slx9_1.36 (VCCAUX), xc6slx9_1.37 (PROGRAM_B_2), xc6slx9_1.42 (VCCO_2), xc6slx9_1.53 (VCCAUX), xc6slx9_1.63 (VCCO_2), xc6slx9_1.65 (IO_L3P_D0_DIN_MISO_MISO1_2), xc6slx9_1.69 (IO_L1N_M0_CMPMISO_2), xc6slx9_1.76 (VCCO_1), xc6slx9_1.86 (VCCO_1), xc6slx9_1.90 (VCCAUX), xc6slx9_1.103 (VCCO_1), xc6slx9_1.122 (VCCO_0), xc6slx9_1.125 (VCCO_0), xc6slx9_1.129 (VCCAUX), xc6slx9_1.135 (VCCO_0); also elsewhere on the board
/FPGA/Clk_A: xc6slx9_1.134 (IO_L34P_GCLK19_0); also elsewhere on the board
/FPGA/Clk_B: xc6slx9_1.14 (IO_L44N_GCLK20_3); also elsewhere on the board
/FPGA/DIV_SW1: xc6slx9_1.132 (IO_L35P_GCLK17_0); also elsewhere on the board
/FPGA/DIV_SW2: xc6slx9_1.143 (IO_L1N_VREF_0); also elsewhere on the board
/FPGA/EN_EXTREF_FILTA: xc6slx9_1.22 (IO_L42P_GCLK25_TRDY2_3); also elsewhere on the board
/FPGA/EN_EXTREF_FILTB: xc6slx9_1.17 (IO_L43P_GCLK23_3); also elsewhere on the board
/FPGA/Ext_Ref_Clk: xc6slx9_1.24 (IO_L41P_GCLK27_3); also elsewhere on the board
/FPGA/RXD: xc6slx9_1.87 (IO_L42N_GCLK6_TRDY1_1); also elsewhere on the board
/FPGA/TCK: xc6slx9_1.109 (TCK); also elsewhere on the board
/FPGA/TDI: xc6slx9_1.110 (TDI); also elsewhere on the board
/FPGA/TDO: xc6slx9_1.106 (TDO); also elsewhere on the board
/FPGA/TMS: xc6slx9_1.107 (TMS); also elsewhere on the board
/USB_JTAG/RXD: xc6slx9_1.88 (IO_L42P_GCLK7_1); also elsewhere on the board
DONE_LED: R11.2, R14.1, xc6slx9_1.71 (DONE_2)
GND: C8.2, C11.2, C12.2, C13.2, C14.2, C15.2, C16.2, C17.2, C18.2, C19.2, C20.2, C21.2, C22.2, C23.2, C24.2, C25.2, C26.2, C27.2, C28.2, C29.2, C30.2, C31.2, C32.2, C33.2, C34.2, C35.2, D1.1 (K), D2.1 (K), D11.1 (K), G1.7 (GND), U3.2 (VSS), U3.6 (A0), U11.4 (GND), xc6slx9_1.3 (GND), xc6slx9_1.13 (GND), xc6slx9_1.25 (GND), xc6slx9_1.49 (GND), xc6slx9_1.54 (GND), xc6slx9_1.60 (IO_L13P_M1_2), xc6slx9_1.68 (GND), xc6slx9_1.73 (SUSPEND), xc6slx9_1.77 (GND), xc6slx9_1.91 (GND), xc6slx9_1.96 (GND), xc6slx9_1.108 (GND), xc6slx9_1.113 (GND), xc6slx9_1.130 (GND), xc6slx9_1.136 (GND), xc6slx9_1.144 (IO_L1P_HSWAPEN_0); also elsewhere on the board
Int_Ref_Clk: G1.8 (CLK), U11.5 (OUT~), xc6slx9_1.56 (IO_L30P_GCLK1_D13_2)
unnamed: C8.1, G1.1 (CTR_V), R16.2, U11.10 (CV)
unnamed: D1.2 (A), R14.2
unnamed: D2.2 (A), R15.2
unnamed: D11.2 (A), R39.2
unnamed: R16.1, U3.1 (VOUT)
SCL_DAC: R8.2, U3.5 (SCL), X1.11, xc6slx9_1.15 (IO_L44P_GCLK21_3)
SDA_DAC: R9.2, U3.4 (SDA), X1.12, xc6slx9_1.16 (IO_L43N_GCLK22_IRDY2_3)
TP1: X1.1, xc6slx9_1.137 (IO_L4N_0)
TP2: X1.2, xc6slx9_1.138 (IO_L4P_0)
TP3: X1.3, xc6slx9_1.139 (IO_L3N_0)
TP4: X1.4, xc6slx9_1.140 (IO_L3P_0)
TP5: X1.5, xc6slx9_1.141 (IO_L2N_0)
TP6: X1.6, xc6slx9_1.5 (IO_L52N_3)
TP7: X1.7, xc6slx9_1.6 (IO_L52P_3)
TP8: X1.8, xc6slx9_1.7 (IO_L51N_3)
TP9: X1.9, xc6slx9_1.8 (IO_L51P_3)
TP10: X1.10, xc6slx9_1.9 (IO_L50N_3)
WORK_LED: R15.1, xc6slx9_1.66 (IO_L2N_CMPMOSI_2)

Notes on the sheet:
PowerPlaneCrossing TPs
PowerPlaneCrossing JTAG
PowerPlaneCrossing I2C
PowerPlaneCrossing RS2232

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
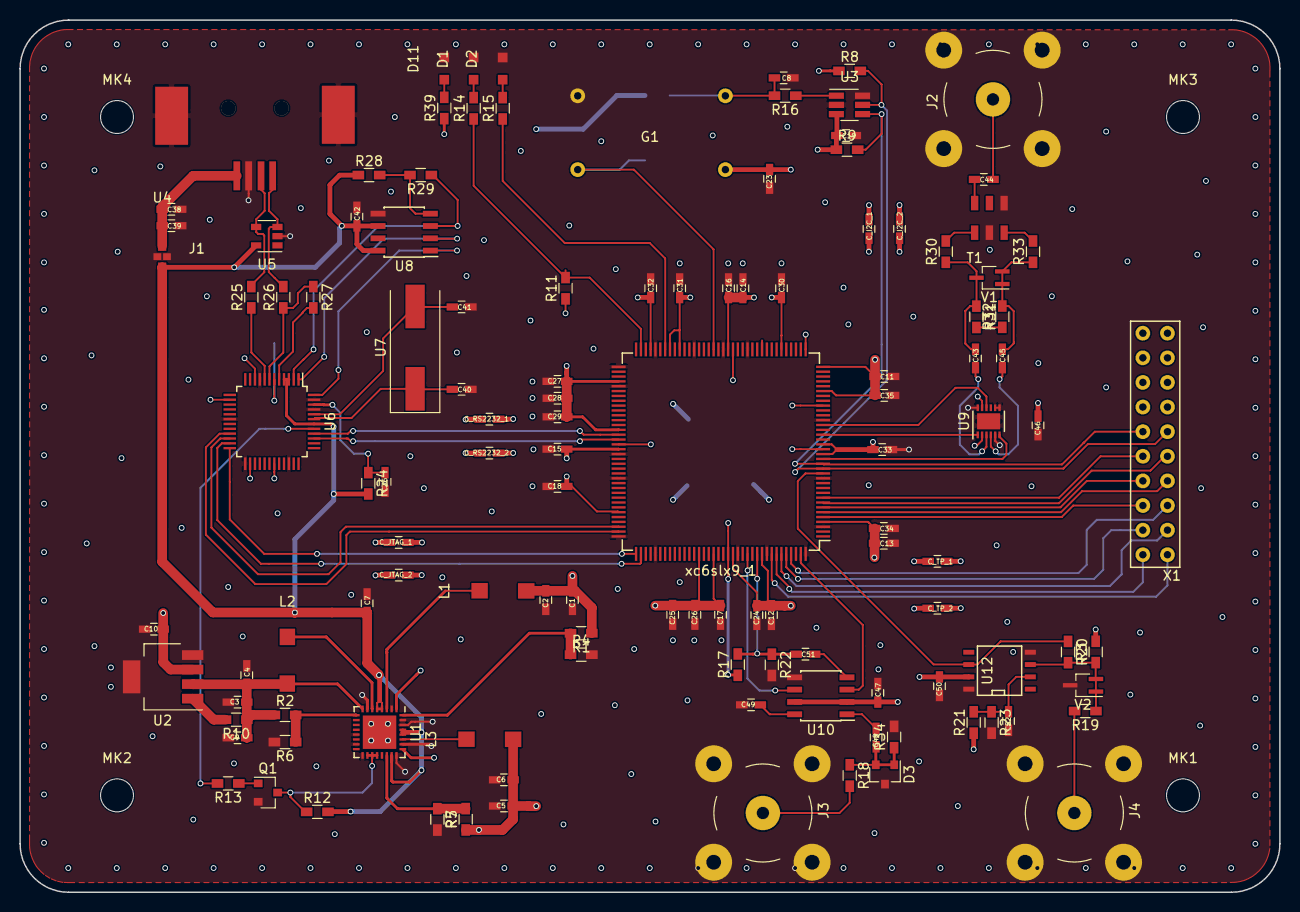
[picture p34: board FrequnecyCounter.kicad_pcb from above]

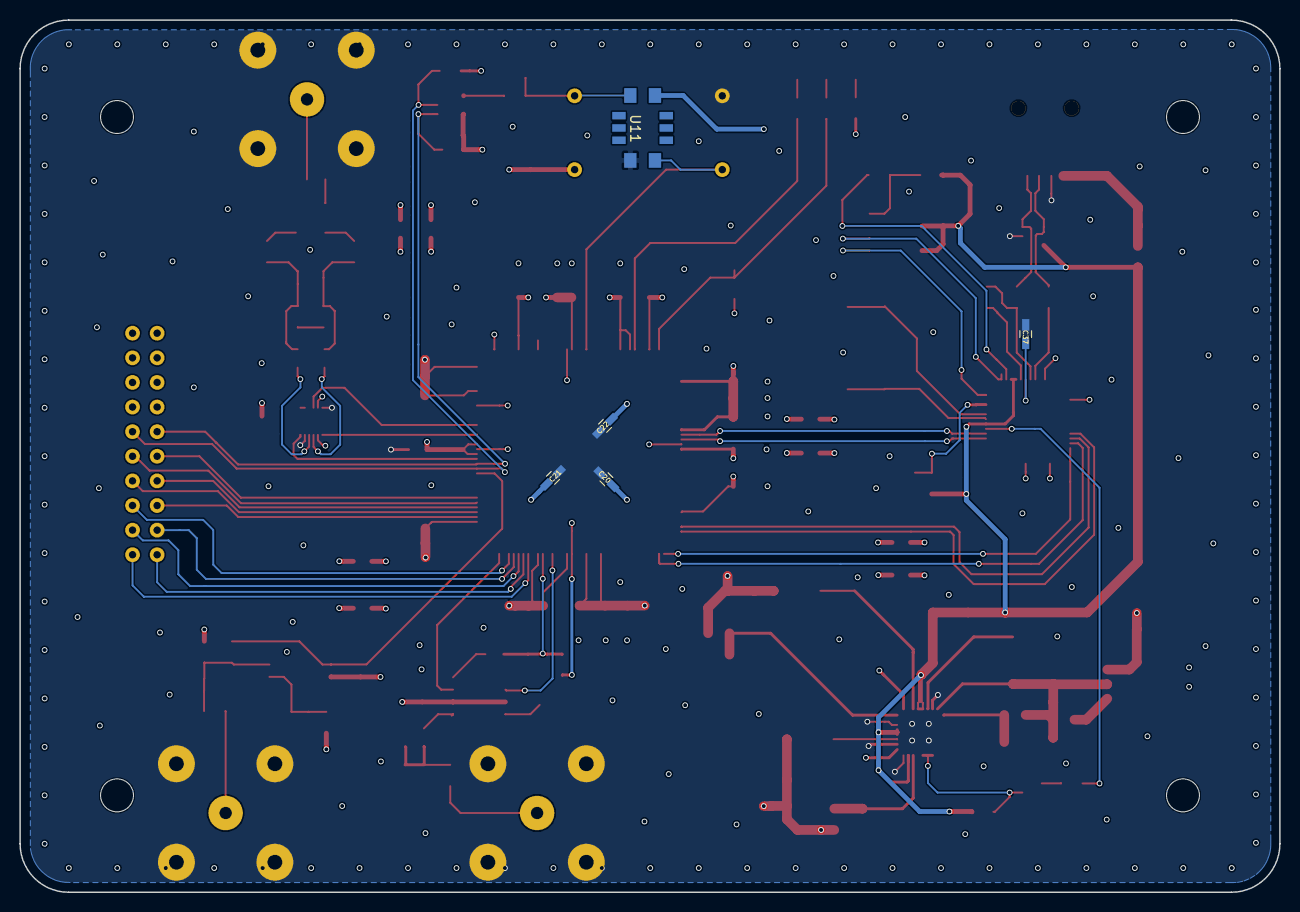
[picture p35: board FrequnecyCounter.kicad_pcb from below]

Board: 4 copper layers, 130.0 x 90.0 mm, 129 parts (5 on the bottom side), 80 nets.

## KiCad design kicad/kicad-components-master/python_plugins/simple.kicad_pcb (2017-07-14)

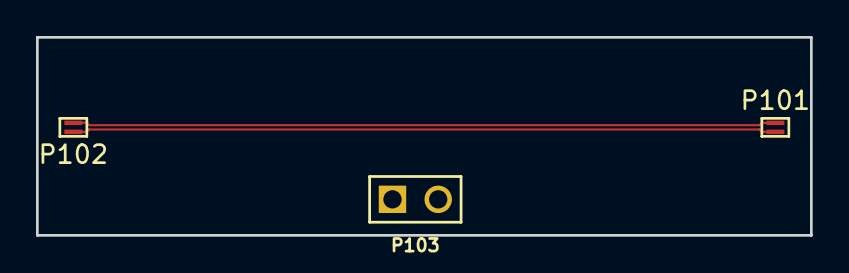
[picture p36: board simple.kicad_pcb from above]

Board: 2 copper layers, 43.0 x 11.0 mm, 3 parts (0 on the bottom side), 3 nets.

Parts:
P101, P102: CONN_01X02; TEST_01x02_05mm
P103: CONN_01X02; pin_array_2x1

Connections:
/HS_N: P101.2, P102.1
/HS_P: P101.1, P102.2
GND: P103.1, P103.2

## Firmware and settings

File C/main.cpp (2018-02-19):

#include <stdio.h>
#include <stdlib.h>

//typedef unsigned long uint32_t;
//I2C--------------------------------------------
volatile unsigned int* I2C_PRER_LO =    (unsigned int*)     0x8004;      //Prescale register low byte
volatile unsigned int* I2C_PRER_HI =    (unsigned int*)     0x8008;      //Prescale register high byte
volatile unsigned int* I2C_CTR =        (unsigned int*)     0x800C;      //Control register
volatile unsigned int* I2C_TXR =        (unsigned int*)     0x8010;      //Transmit register
volatile unsigned int* I2C_RXR =        (unsigned int*)     0x8014;      //Receive register
volatile unsigned int* I2C_CR =         (unsigned int*)     0x8018;      //Command register
volatile unsigned int* I2C_SR =         (unsigned int*)     0x801C;      //Status register
//IO-------------------------------------------------------
volatile unsigned int* LEDS =           (unsigned int*)     0x8020;
volatile unsigned int* TestStatus =     (unsigned int*)     0x8030;
//FC-------------------------------------------------------
volatile unsigned int* ChannelConfig =  (unsigned int*)     0xA004;      //write
volatile unsigned int* Timebase =       (unsigned int*)     0xA008;      //write
volatile unsigned int* CounterReset =   (unsigned int*)     0xA00C;      //write
volatile unsigned int* StartMeas =      (unsigned int*)     0xA010;      //write
volatile unsigned int* MeasValueValid = (unsigned int*)     0xA014;      //read
volatile unsigned int* RefCountVal_Hi =   (unsigned int*)   0xA020;      //read
volatile unsigned int* RefCountVal_HiMi =   (unsigned int*) 0xA024;      //read
volatile unsigned int* RefCountVal_MiLo =   (unsigned int*) 0xA028;      //read
volatile unsigned int* RefCountVal_Lo =   (unsigned int*)   0xA02C;      //read
volatile unsigned int* MeasCountVal_Hi =  (unsigned int*)   0xA030;      //read
volatile unsigned int* MeasCountVal_HiMi =  (unsigned int*) 0xA034;      //read
volatile unsigned int* MeasCountVal_MiLo =  (unsigned int*) 0xA038;      //read
volatile unsigned int* MeasCountVal_Lo =  (unsigned int*)   0xA03C;      //read
//UART-----------------------------------------------------
volatile unsigned int* RxData =         (unsigned int*)     0xE004;      //read
volatile unsigned int* TxData =        (unsigned int*)      0xE008;        //write
volatile unsigned int* tx_busy =        (unsigned int*)     0xE00C;      //read
volatile unsigned int* tx_enable =      (unsigned int*)     0xE010;      //write
//Calib----------------------------------------------------
volatile unsigned int DAC_DATA_HI;
volatile unsigned int DAC_DATA_LO;
volatile unsigned int DAC_Reg;
volatile unsigned int DAC_EEPROM_LO;
volatile unsigned int DAC_EEPROM_HI;
volatile unsigned int Write_State = 0;
volatile unsigned int Read_State;
volatile unsigned int test;
volatile unsigned int i;
//---------------------------------------------------
int i2c_master_init (void);
int i2c_write(unsigned int);
int i2c_read(void);
volatile int d = 0;
int sendBytes = 0;
unsigned int MeasCount;
unsigned int RefCount;
unsigned int DataTx = 0;
unsigned int MeasCount1 = 0;
unsigned int MeasCount2 = 0;
unsigned int MeasCount3 = 0;
unsigned int MeasCount4 = 0;

const int MaxVCTOXOCtrlVal = 3723;
const int TypVCTOXOCtrlVal = 2048;
const int MinVCTOXOCtrlVal = 373;
const int MaxAOCJY1CtrlVal = 2668;
const int TypAOCJY1CtrlVal = 2048;
const int MinAOCJY1CtrlVal = 1428;

typedef enum
{
    Startup,
    Idle,
    Measure,
    Calib,
    Transmit
} my_state_t;

int main(void)
{
    my_state_t state = Startup;
    //i2c_master_init();
    int i = 0;
    while(1)
    {
        //i2c_write(2048);
        switch(state)
        {
            case Startup:
                i2c_master_init();
                state = Idle;
            break;
            case Idle:
                if(((*RxData)&0x80) == 0x80)
                {
                    *ChannelConfig = ((*RxData)&0x03);
                    *Timebase = ((*RxData)&0x0C) >> 2;
                    *LEDS = *RxData;
                    *CounterReset = 0;

                    state = Measure;
                    *StartMeas = 1;

                }
                if(((*RxData)&0x40) == 0x40)
                {
// ;
                    //*CalibOsc = 1;
                    //state = Calib;
                }
            break;

            case Measure:
                //*LEDS = *MeasValueValid;
                if(((*MeasValueValid)&0x01) == 0x01)
                {
                    *StartMeas = 0;
//                    MeasCount1 = *MeasCountVal_Hi;
//                    MeasCount2 = *MeasCountVal_HiMi;
//                    MeasCount3 = *MeasCountVal_MiLo;
//                    MeasCount4 = *MeasCountVal_Lo;
                    MeasCount = ((*MeasCountVal_Hi) << 24)&0xFF000000;
                    MeasCount |= (((*MeasCountVal_HiMi) << 16)&0x00FF0000);
                    MeasCount |= (((*MeasCountVal_MiLo) << 8) &0x0000FF00);
                    MeasCount |= ((*MeasCountVal_Lo)&0x000000FF);
//                    if(MeasCount == 0x00000C9A)
//                        *LEDS = 0xFF;
                    RefCount = ((*RefCountVal_Hi) << 24)&0xFF000000;
                    RefCount |= (((*RefCountVal_HiMi) << 16)&0x00FF0000);
                    RefCount |= (((*RefCountVal_MiLo) << 8) &0x0000FF00);
                    RefCount |= ((*RefCountVal_Lo)&0x000000FF);
                    state = Transmit;
                    sendBytes = 0x00;
//                    MeasCount = 0x12345678;
//                    RefCount =  0x9ABCDEF0;
                    *CounterReset = 1;
                }
            break;

//            case Calib:
//
//
//            break;

            case Transmit:
                if(((*tx_busy)&0x01) == 0x00)
                {
                    *StartMeas = 0;
//                    if(sendBytes < 8)
//                    {
//                        if(sendBytes == 0)
//                        {
//                            DataTx = MeasCount;
//                        }
//                        if(sendBytes == 4)
//                        {
//                            DataTx = RefCount;
//                        }
//                        else
//                        {
//                            *TxData = (DataTx>>24);
//                            *tx_enable = 1;
//                            *tx_enable = 0;
//                            DataTx = DataTx << 8;
//                            sendBytes++;
//                        }
//                        if(sendBytes == 8)
//                        {
//                            state = Idle;
//                            //sendBytes = 0x00;
//                            *TxData = 0x00;
//                            //*CounterReset = 0;
//                            *tx_enable = 0x00;
//                        }
//
//                    }
                    if(sendBytes == 0)
                    {
                        DataTx = MeasCount;
                    }
                    if(sendBytes == 4)
                    {
                         DataTx = RefCount;
                    }
                    if(sendBytes == 8)
                    {
                        *tx_enable = 0;
                        *TxData = 0;
                        state = Idle;
                    }
                    if((((*RxData)&0x70)>>4) == sendBytes)
                    {
                        *TxData = (DataTx>>24);
                        *tx_enable = 1;
                        *tx_enable = 0;
                        DataTx = DataTx << 8;
                        sendBytes++;
                    }
                }
//                        if(sendBytes < 4)
//                        {
//                            *LEDS = (MeasCount>>24);
//                            *TxData = (MeasCount>>24);
//                            *tx_enable = 1;
//                            *tx_enable = 0;
//                            MeasCount = MeasCount << 8;
//                            sendBytes++;
//                        }
//                        if(sendBytes >= 4 && sendBytes < 8)
//                        {
//                            *LEDS = (RefCount>>24);
//                            *TxData = (RefCount>>24);
//                            *tx_enable = 1;
//                            *tx_enable = 0;
//                            RefCount = RefCount << 8;
//                            sendBytes++;
//                        }
//                    }
//                }
//                else if(sendBytes == 8)
//                {
//                    *tx_enable = 0;
//                    *TxData = 0x00;
//                    sendBytes = 0;
//                    state = Idle;
//                }

            break;
        }
//        i2c_write(0x800);
//        *tx_enable = 1;
//        *TxData = 0xAA;
//        *LEDS = *I2C_SR;

    }


//        i2c_read();
//    }
}

int i2c_master_init(void)
{
    *I2C_PRER_HI = 0x00000000;  //Set Prescale to Register 0x14 ==> (10MHz/500kHz)-1
    *I2C_PRER_LO = 0x00000013;
    *I2C_CTR = 0x00000080;
    *I2C_TXR = 0x00000000;
    Write_State = 0;
    i2c_write(2048);

}

int i2c_write(unsigned int Data)
{
    *LEDS = *I2C_SR;
    int i = 0;
    for(;Write_State < 4;)
    {
        if(/*(((*I2C_SR)&0x00080) == 0x00000000)&& */Write_State == 0)               //1 byte
        {
            *I2C_CR = 0x000000090;      //STA,WR
            *I2C_TXR = 0x000000C8;      //C0//I2C DAC adress + write_bit
            while(((*I2C_SR)&0x02) == 0x02 /*&&  i != 0x0000FFFF*/)
            {i++;
            }
             Write_State = 1;
             *TestStatus = 1;
        }
    /////////////////////////////////////////////////////////////
        else if(/*(((*I2C_SR)&0x00080) == 0x00000000)&& */Write_State == 1)  //2 byte
        {
            //*TestStatus = 0;
            *I2C_TXR = 0x00000060;     //60 //C2,C1,C0,X,X,PD1,PD0
            *I2C_CR = 0x000000010;      //WR
            while(((*I2C_SR)&0x02) == 0x02 /*&&  i != 0x0000FFFF*/)
            {i++;
            }
                Write_State = 2;
        }
    //////////////////////////////////////////////////////////
        else if(/*(((*I2C_SR)&0x00080) == 0x00000000)&& */Write_State == 2)  //3 byte    Mask all relevat bits and look for now failure (E3)
        {
            *I2C_TXR =  (Data >> 4);      //D11,D10,D9,D8,D7,D6,D5,D4  Data >> 4
            *I2C_CR = 0x000000010;      //WR
            while(((*I2C_SR)&0x02) == 0x02 /*&&  i != 0x0000FFFF*/)
            {i++;
            }
            Write_State = 3;
        }
    ///////////////////////////////////////////////////////////////
        else if(/*(((*I2C_SR)&0x00080) == 0x00000000)&& */Write_State == 3)  //4 byte
        {
            *I2C_TXR = ((Data&0x0F) << 4);      //D3,D2,D1,D0,X,X,X,X
            *I2C_CR = 0x000000050;      //WR,STO
            while(((*I2C_SR)&0x02) != 0x02 /*&&  i != 0x0000FFFF*/)
            {i++;
            }
            Write_State = 4;
            *I2C_CR = 0x000000040;
        }
        *LEDS = *I2C_SR;
    }
    Write_State = 0;
}

int i2c_read(void)
{
    unsigned int i = 0;
    if((((*I2C_SR)&0x00080) == 0x00000000)&& Read_State == 0)               //1 byte Mask(E3)
    {
        *I2C_CR = 0x0000000A0;      //STA,RD
        *I2C_TXR = 0x000000C1;      //I2C DAC adress + read_bit
        while(((*I2C_SR)&0x00000002) == 0x00000002/* ||  i != 0x0000FFFF*/)
        {/*i++;*/
        }
        Read_State = 1;
    }
////////////////////////////////////////////////////////////////////////////
    if((((*I2C_SR)&0x00080) == 0x00000000)&& Read_State == 1)               //2 byte
    {
        *I2C_CR = 0x000000020;      //RD
        DAC_Reg = *I2C_RXR;         //DAC Registers
        while(((*I2C_SR)&0x00000002) == 0x00000002/* ||  i != 0x0000FFFF*/)
        {/*i++;*/
        }
        Read_State = 2;
    }
/////////////////////////////////////////////////////////////////////////////
    if((((*I2C_SR)&0x00080) == 0x00000000)&& Read_State == 2)              //3 byte
    {
        *I2C_CR = 0x000000020;      //RD
        DAC_DATA_HI = *I2C_RXR;         //Data D11..D4
        while(((*I2C_SR)&0x00000002) == 0x00000002/* ||  i != 0x0000FFFF*/)
        {/*i++;*/
        }
        Read_State = 3;
    }
/////////////////////////////////////////////////////////////////////////////
    if((((*I2C_SR)&0x00080) == 0x00000000)&& Read_State == 3)               //4 byte
    {
        *I2C_CR = 0x000000020;      //RD
        DAC_DATA_LO = *I2C_RXR;         //Data D3..D0
        while(((*I2C_SR)&0x00000002) == 0x00000002/* ||  i != 0x0000FFFF*/)
        {/*i++;*/
        }
        Read_State = 4;
    }
///////////////////////////////////////////////////////////////////////////////
    if((((*I2C_SR)&0x00080) == 0x00000000)&& Read_State == 4)               //5 byte
    {
        *I2C_CR = 0x000000020;      //RD
        DAC_EEPROM_HI = *I2C_RXR;         //Data D11..D08
        while(((*I2C_SR)&0x00000002) == 0x00000002/* ||  i != 0x0000FFFF*/)
        {/*i++;*/
        }
        Read_State = 5;
    }
///////////////////////////////////////////////////////////////////////////////
    if((((*I2C_SR)&0x00080) == 0x00000000)&& Read_State == 5)              //6 byte
    {
        *I2C_CR = 0x000000020;      //RD
        DAC_EEPROM_LO = *I2C_RXR;         //Data D7..D0
        while(((*I2C_SR)&0x00000002) == 0x00000002/* ||  i != 0x0000FFFF*/)
        {/*i++;*/
        }
        Read_State = 0;
        *I2C_CR = 0x000000040;
    }
    if(Read_State > 0 && (*I2C_SR&0x40) == 0)
    {
        *I2C_CR = 0x000000040;
    //        *I2C_CTR = 0x00;
    //        while(*I2C_CTR != 0x00)
    //        {
    //            *I2C_CTR = 0x00;
    //        }
        *I2C_TXR = 0x00;
    }
}

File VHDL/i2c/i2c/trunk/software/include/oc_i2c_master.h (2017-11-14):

/*
/////////////////////////////////////////////////////////////////////
////                                                             ////
////  Include file for OpenCores I2C Master core                 ////
////                                                             ////
////  File    : oc_i2c_master.h                                  ////
////  Function: c-include file                                   ////
////                                                             ////
////  Authors: Richard Herveille (richard@asics.ws)              ////
////           Filip Miletic                                     ////
////                                                             ////
////           www.opencores.org                                 ////
////                                                             ////
/////////////////////////////////////////////////////////////////////
////                                                             ////
//// Copyright (C) 2001 Richard Herveille                        ////
////                    Filip Miletic                            ////
////                                                             ////
//// This source file may be used and distributed without        ////
//// restriction provided that this copyright statement is not   ////
//// removed from the file and that any derivative work contains ////
//// the original copyright notice and the associated disclaimer.////
////                                                             ////
////     THIS SOFTWARE IS PROVIDED ``AS IS'' AND WITHOUT ANY     ////
//// EXPRESS OR IMPLIED WARRANTIES, INCLUDING, BUT NOT LIMITED   ////
//// TO, THE IMPLIED WARRANTIES OF MERCHANTABILITY AND FITNESS   ////
//// FOR A PARTICULAR PURPOSE. IN NO EVENT SHALL THE AUTHOR      ////
//// OR CONTRIBUTORS BE LIABLE FOR ANY DIRECT, INDIRECT,         ////
//// INCIDENTAL, SPECIAL, EXEMPLARY, OR CONSEQUENTIAL DAMAGES    ////
//// (INCLUDING, BUT NOT LIMITED TO, PROCUREMENT OF SUBSTITUTE   ////
//// GOODS OR SERVICES; LOSS OF USE, DATA, OR PROFITS; OR        ////
//// BUSINESS INTERRUPTION) HOWEVER CAUSED AND ON ANY THEORY OF  ////
//// LIABILITY, WHETHER IN  CONTRACT, STRICT LIABILITY, OR TORT  ////
//// (INCLUDING NEGLIGENCE OR OTHERWISE) ARISING IN ANY WAY OUT  ////
//// OF THE USE OF THIS SOFTWARE, EVEN IF ADVISED OF THE         ////
//// POSSIBILITY OF SUCH DAMAGE.                                 ////
////                                                             ////
/////////////////////////////////////////////////////////////////////
*/

/*
 * Definitions for the Opencores i2c master core
 */

/* --- Definitions for i2c master's registers --- */

/* ----- Read-write access                                            */

#define OC_I2C_PRER_LO 0x8020     /* Low byte clock prescaler register  */
#define OC_I2C_PRER_HI 0x8021     /* High byte clock prescaler register */
#define OC_I2C_CTR     0x8022     /* Control register                   */

/* ----- Write-only registers                                         */

#define OC_I2C_TXR     0x8023     /* Transmit byte register             */
#define OC_I2C_CR      0x8024     /* Command register                   */

/* ----- Read-only registers                                          */

#define OC_I2C_RXR     0x8023     /* Receive byte register              */
#define OC_I2C_SR      0x8024     /* Status register                    */

/* ----- Bits definition                                              */

/* ----- Control register                                             */

#define OC_I2C_EN (1<<7)        /* Core enable bit:                   */
                                /*      1 - core is enabled           */
                                /*      0 - core is disabled          */
#define OC_I2C_IEN (1<<6)       /* Interrupt enable bit               */
                                /*      1 - Interrupt enabled         */
                                /*      0 - Interrupt disabled        */
                                /* Other bits in CR are reserved      */

/* ----- Command register bits                                        */

#define OC_I2C_STA (1<<7)       /* Generate (repeated) start condition*/
#define OC_I2C_STO (1<<6)       /* Generate stop condition            */
#define OC_I2C_RD  (1<<5)       /* Read from slave                    */
#define OC_I2C_WR  (1<<4)       /* Write to slave                     */
#define OC_I2C_ACK (1<<3)       /* Acknowledge from slave             */
                                /*      1 - ACK                       */
                                /*      0 - NACK                      */
#define OC_I2C_IACK (1<<0)      /* Interrupt acknowledge              */

/* ----- Status register bits                                         */

#define OC_I2C_RXACK (1<<7)     /* ACK received from slave            */
                                /*      1 - ACK                       */
                                /*      0 - NACK                      */
#define OC_I2C_BUSY  (1<<6)     /* Busy bit                           */
#define OC_I2C_TIP   (1<<1)     /* Transfer in progress               */
#define OC_I2C_IF    (1<<0)     /* Interrupt flag                     */

/* bit testing and setting macros                                     */

#define OC_ISSET(reg,bitmask)       ((reg)&(bitmask))
#define OC_ISCLEAR(reg,bitmask)     (!(OC_ISSET(reg,bitmask)))
#define OC_BITSET(reg,bitmask)      ((reg)|(bitmask))
#define OC_BITCLEAR(reg,bitmask)    ((reg)|(~(bitmask)))
#define OC_BITTOGGLE(reg,bitmask)   ((reg)^(bitmask))
#define OC_REGMOVE(reg,value)       ((reg)=(value))

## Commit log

2017-06-15 Anpassungen und Änderungen von einigen präverierten Bauteilen
2017-07-14 Added planing BOM
2017-07-14 Add hardware layout
    [1593K_Enclosure.kicad_pcb, 1593K_Enclosure.sch, Arduino_As_Uno.kicad_pcb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]
2017-07-17 Layout [in progress]
    [FPGA.sch, FrequnecyCounter.kicad_pcb, FrequnecyCounter.sch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]
2017-08-22 Update Layout and Schematic [On Change]
    [FPGA.sch]
2017-08-30 - Delete multiple and useless files - Add DataController and Processor
    [FPGA.sch]
2017-09-18 Add working DataProcesssingUnit for the UART data
2017-09-19 Layout changes [in progress]
    [FPGA.sch, FrequnecyCounter.kicad_pcb, USB_JTAG.sch]
2017-10-09 Rework hardware schematic [in progress]
    [FPGA.sch, Power_Supply.sch, Signal_Input.sch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]
2017-10-10 Reworked schematic and layout [to review]
    [FPGA.sch, FrequnecyCounter.kicad_pcb, FrequnecyCounter.sch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]
2017-10-11 Remove design errors and changes some footprints [to review]
    [FPGA.sch, FrequnecyCounter.kicad_pcb, Power_Supply.sch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]
2017-10-11 swaping power-plane layer with ground layer [to review]
    [FrequnecyCounter.kicad_pcb]
2017-10-26 some small schematic and layout changes [completed]
    [FPGA.sch, FrequnecyCounter.kicad_pcb, FrequnecyCounter.sch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]
2017-10-31 Add VHDL I2C master controller with wishbone interface
2017-11-02 Changed some Footprints to improve handsoldering
    [FrequnecyCounter.kicad_pcb]
2017-11-02 Small layout and schematic changes
    [FPGA.sch, FrequnecyCounter.kicad_pcb, FrequnecyCounter.sch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]
2017-11-06 Small schematic and layout changes
    [FPGA.sch, FrequnecyCounter.kicad_pcb, FrequnecyCounter.sch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]
2017-11-06 Layout changes to guarantee the fit of the PCB housing
    [FrequnecyCounter.kicad_pcb]
2017-11-07 Changed layout to guarantee to fit the housing
    [FrequnecyCounter.kicad_pcb]
2017-11-07 Relocated overhanging USB connector
    [FrequnecyCounter.kicad_pcb]
2017-11-09 Placed vias to stitch gnd planes together | Add blank pcb frame | Changed some panel positions
    [FrequnecyCounter.kicad_pcb]
2017-11-14 Change location of i2c folder ==> Moved to VHDL
2017-11-14 layout commit after generating Gerberfiles
    [FrequnecyCounter.kicad_pcb, Signal_Input.sch]
2017-11-14 Changed location of i2c folder to VHDL
2017-11-14 Add adjusted i2c_master_top.vhd for Zealot & Zpu4
2017-11-17 Changed I2C controller register addresses to solve communication issues
2017-11-21 Changed again I2C controller register adresses to reduce unnecessary accesses/traffic to the controller registers
2017-12-01 Changed output datatype to std_logic_vector to get a consistent datatpye in the hole project
2017-12-01 Add Escaping.vhd for the UART COM
2017-12-15 Add UartTop + new project structure
2017-12-15 Add I2CTop + new project structure
2018-01-09 Changed UART Config
2018-01-16 Bug fix: change uart frequency to clk_speed value
2018-02-12 Changed some component values to increase the fit & Changed power-supply of the eeprom to use the PWR_EN of the FT2232D
    [FrequnecyCounter.kicad_pcb, Signal_Input.sch, USB_JTAG.sch]
2018-02-12 Set Divider of channel A divider to /8 & Enabled FILTER for both channels of LTC6957
2018-02-19 Add folder FTDI with FT_Prog Template & ft2232 config-file for openocd
    [ft2232-jtag.cfg]
2018-08-08 clean up in layout & add exports (assembly drawings)
    [FPGA.sch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]
2018-08-23 new bitstream with non specific pin assignment & changed TP assignment
